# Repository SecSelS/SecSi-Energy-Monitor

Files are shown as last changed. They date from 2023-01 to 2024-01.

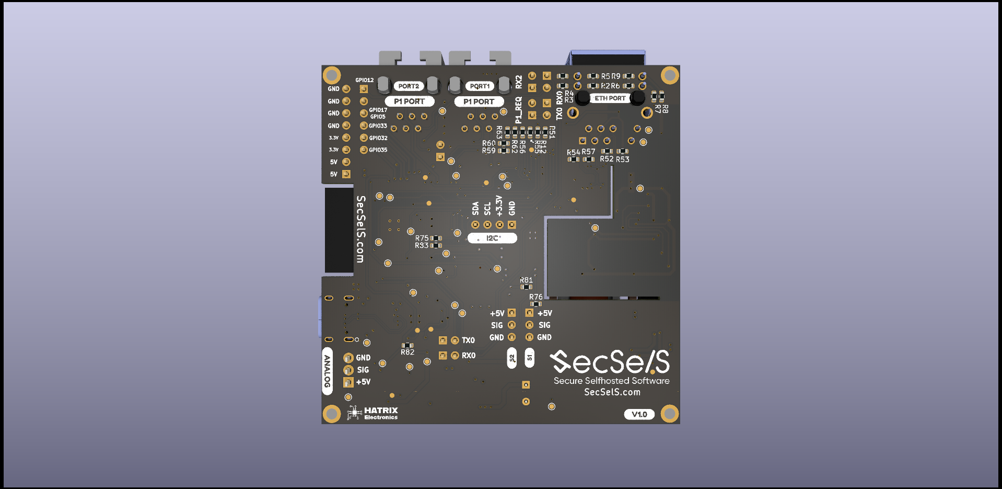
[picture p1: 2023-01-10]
Render/P1_shield_board_bottom.png

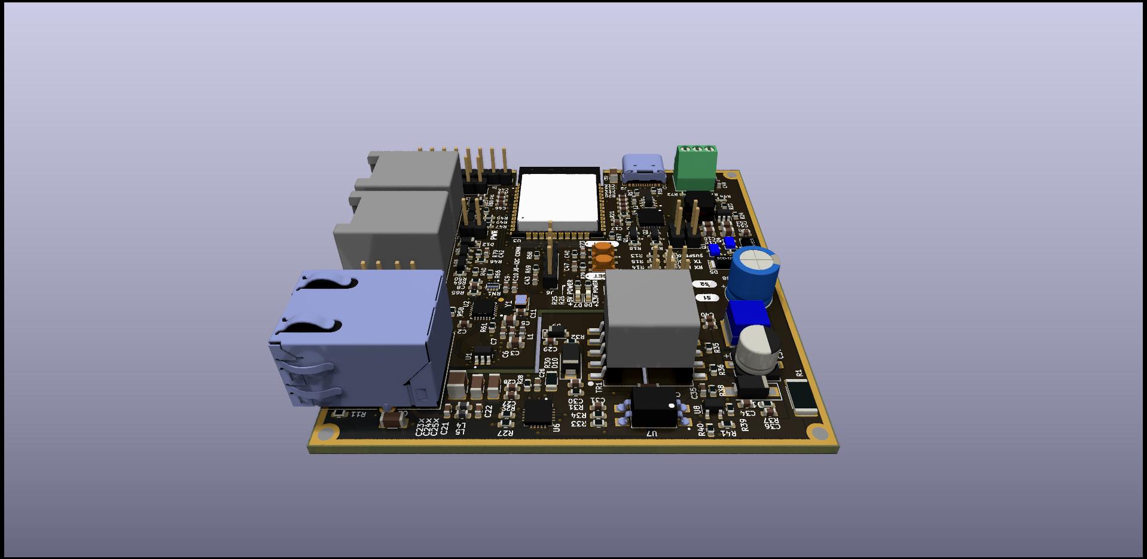
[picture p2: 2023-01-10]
Render/P1_shield_board_4.jpg

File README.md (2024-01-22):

<p align="center"><a href="https://secsels.com">SecSelS - Secure Selfhosted Software<a><p>
  
<br>
</br>
<h1 align="center" text-align="center" display="center"><a href="https://secsels.com">SecSi Energy Monitor<a></h1>

<a href="https://secsels.com">SecSelS.com</a> is a company specialized in installing, programming and inventing solutions, especially in the smart home sector. Together with <a href="https://www.luxmetering.lu/">Luxmetering</a> we invented this board to hookup every P1 meter in Luxemburg and other countries having smart meters on the P1 standard. In light of the energy-crisis and to help everyone to make his or her home or business more sustainable, we decided to opensource this device and make it compatible not only with our smart home solution, but also with other opensource smart home systems. 

You can buy a manufactured and CE-tested Version of the device for home and industry here:

<a href="https://shop.secsels.com">shop.secsels.com</a>

## Features List ##
###
* 2x P1 Port reader connected to Hardware-Uart -> read two meters precisely at the same time.
  * See the issues-sector for more information about encryptted meters
* Hardware-Uart Jumpers -> Use second Uart either for second P1, or for USB-C connection to program the board
* P1 Passthrough Jumper -> Connect either a second P1 device to the first P1, or directly to the ESP32
* Lan, Wifi and Bluetooth interfaces
* 2x Pulsecounter-Interface -> Hookup your watermeter or solar-system, and read the data.
* Additional GPIO's for additional sensors
* Multiple Powersupply options
  * P1 Port -> Directly get your supply from the P1 meter
  * POE -> Capable of POE powersupply
  * USB-C
###

## How to flash ESPHome ##
  ### Prerequisites ###
  * First make sure you have set the jumpers right for flashing. Jumpers JP7 and JP8 must be connected, UART0 is used for programming. Also make sure you don't connect any P1 device yet!
  * This tutorial is meant for the setup with <a href="https://esphome.io/">ESPHome</a>, so make sure you install it on you PC if you dont run it somewhere else. Read the guide for installing ESPHome on your PC -> https://esphome.io/guides/installing_esphome.html
  * The Yaml-Files are preprogrammed for Luxembourg, but you can alter them to work with Belgium P1 too. Also pulse counters and other devices are not included, but you can always append them to your configuration and connect them to the board. If you want to use the board for other purposes as P1 interface, you can write your own yaml of course.
  * Make sure you have <a href="https://github.com/esphome/esphome-flasher">esphome-flasher</a> installed, as the config is the easiest with that.
  * Download the <a href="#top">secsi_energy_monitor_production_lu.yaml</a> and the <a href="#top">secrets.yaml</a> to your PC.
  * If you're in Luxemburg, make sure you have your DSMR-Keys ready. In Luxemburg you can ask  your energy-provider for them per Mail.
  ### First Steps ###
  * Adjust the secrets.yaml to your data (fill in wifi data and your dsmr-key). If you don't define wifi-networks yourself but use the dashboard_import function, make sure to delete the wifi secrets.
    * On Windows you can use Notepad++ for this task, on linux use your favorite editor
    * Make sure you noted the path to your file, as you'll need it in the next step
  * Run the ESPHome commandline interface, and issue the ```run esphome secsi_energy_monitor_production_lu.yaml compile``` in your downloaded config- and secrets.yaml folder and navigate to the <NODE_NAME>/.pioenvs/<NODE_NAME>/ folder. There you will find a firmware.bin file, this is the binary you will upload.
    * Follow the instructions of the interface, and pay special attention to log output
  * Plug the Board over USB-C cable to your PC
  * Use <a href="https://github.com/esphome/esphome-flasher">esphome-flasher</a> to flash the generated config on the board. Kindly refere to their how-to.
  * If everything goes well, you now have a working P1 meter! Enjoy =)
### Additional configuration ###
  * If you use a second P1 meter, make sure to set the jumpers right! Kindly refer to the hardware documentation in the repository, and the known issues for Luxemburg
### Known issues, To be done and Limitations ###
  * When you use Ethernet, GPIO17 is not usable for external sensors/actors. He than is used as CLK_OUT so this is expected.
  
## Thank You! ##
  We wanted to thank the opensource-community and especially the developers of <a href="https://esphome.io/">ESPHome</a>! Without you, our device would not be possible! We hope that we can give back more to the community in the future. If you like our device, don't hesitate to star it =). If you don't want to configure it yourself, or have problems doing it, simply contact our company and we will find a way to help you =) -> https://secsels.com/kontakt/

<br />This work is licensed under a <a rel="license" href="http://creativecommons.org/licenses/by-sa/4.0/">Creative Commons Attribution-ShareAlike 4.0 International License</a>.

SecSels's logo and branding is used throughout this project. These brandings are Copyright protected by Franco Investments (SecSelS) and all rights are reserved. You may not distribute derivative works or products bearing the mentioned logos. Derivative works should remove all these brandings, and the license does not give any right of usage to these or other brandings used on the product.

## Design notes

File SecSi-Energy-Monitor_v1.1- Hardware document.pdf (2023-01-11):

# SecSi-Energy-Monitor

Version 1.1

Hardware document

HATRIX-ELECTRONICS

## TABLE OF CONTENTS

## 1. Introduction

SecSi-Energy-Monitor is a innovative device developed for use in smart home system. Motivation comes from need to integrate a lot of different modules on a single board and thus create more centralized system.

SecSi-Energy-Monitor provides next functionalities:

- WiFi;
- Bluetooth;
- POE (Power over Ethernet);
- Ethernet communication;
- 2x P1 Ports (Power and communication);
- I2C - for example display;
- Programming MCU over WiFi or USB-C;
- 1x Analog sensor;
- 2x Pulse sensors;
- 6x GPIOs;

## 2. Hardware considerations

P1 Shield board consists next modules (Figure 1):

1. MCU;
2. PSU;
3. POE;
4. USB to Serial converter;
5. Ethernet;
6. P1 Port;

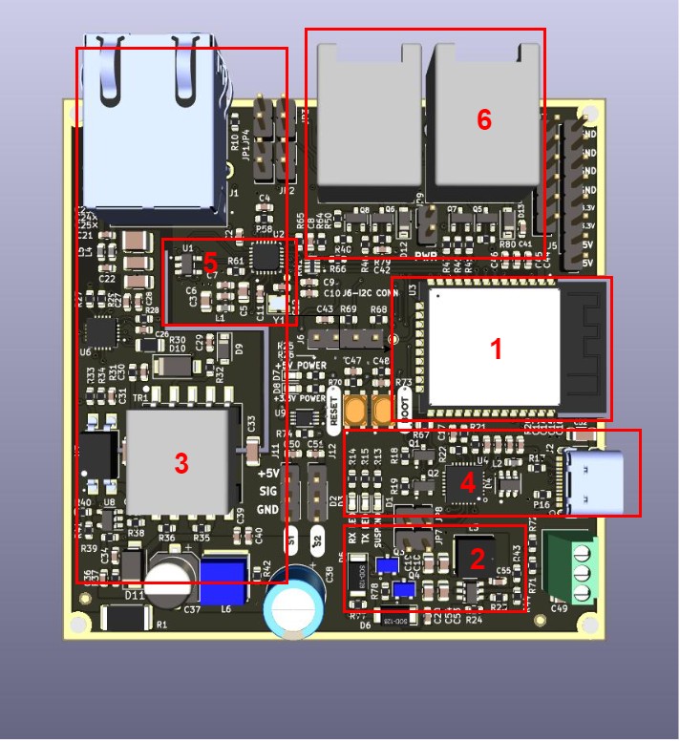
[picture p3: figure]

Figure 1: 3D View - Modules

### PSU:

The power supply of the entire board is realized with DC-DC converter (AP62200WU-7) which works in BUCK configuration. The output voltage is +3.3V and maximum output current is 2A.

DC-DC accepts 5V at it’s input from 3 different sources using control power switch implemented with two P-type mosfets. Source with the highest priority is POE, followed by USB, and the lowest priority is P1 Port. Source selection is done automatically. There is no conflicts if only one source is connected or if combinations of sources are connected.

### POE:

POE can be used to power the board. Segment is realized using IC (SI3404) whose role is to convert input voltage from RJ45 and adjust it for use. The POE standard applied to the board is IEEE 802.3 Type 1 and the board is galvanic isolated (1.5kV) using a transformer.

### USB to Serial:

Module is used for communication and programming of the microcontroller that is placed on the board. Its role is to convert communication between USB and UART. An important item added to this module is the auto-boot function. Auto-boot function represents programming without pressing the boot button, you only need to connect the USB and start programming, the board will do the rest and inform you when programming is finished.

### Ethernet:

Ethernet is designed for speed’s up to 100Mb/s in configuration “Auto-negotiation enabled”.

### P1 Port:

Module is used for providing power to board and communication using P1 port specification with communication baud rate up to 115 200.

## 3. Software consideration

### MCU-ESP32:

MCU is the most important part of the board, it controls and communicates with the modules. ESP32 has integrated Wi-Fi and Bluetooth communication. Programming of the controller is done using USB through a USB to Serial converter. There are two push-buttons on the board, BOOT and RESET. The reset button resets the controller, while the boot button is used during programming. Next figure represents device block diagram and pinout (Figure 2):

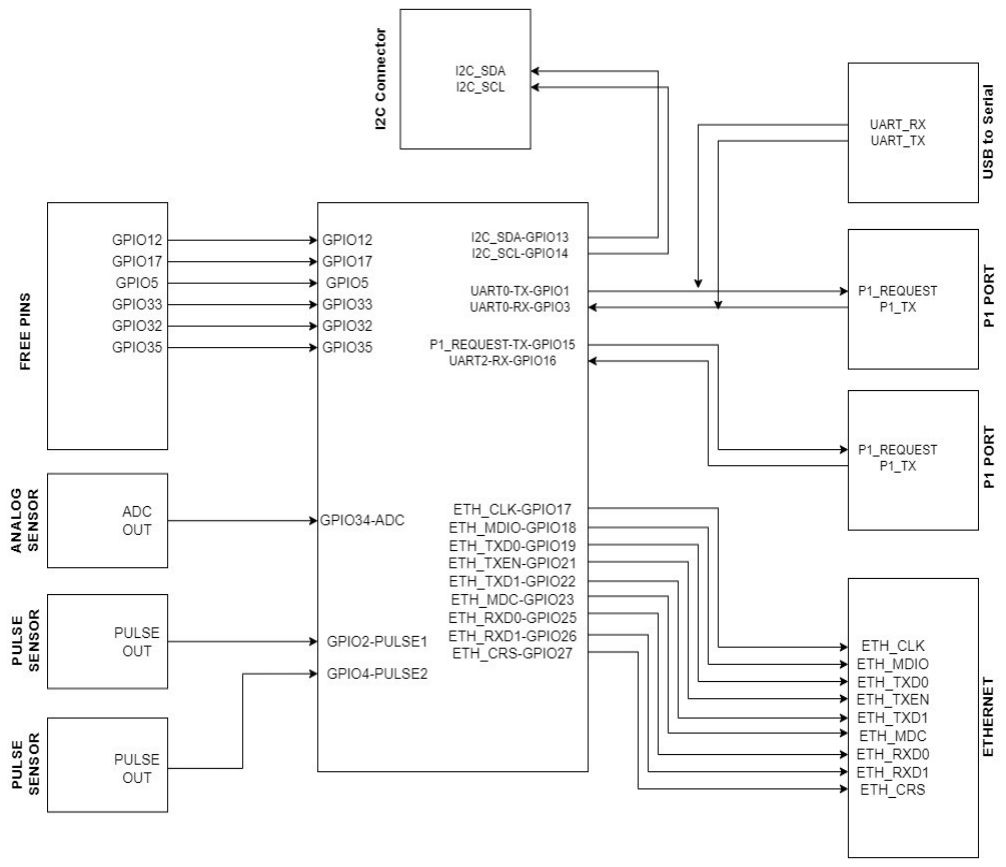
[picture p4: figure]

Figure 2: Block diagram and pinout

ESP32 uses UART, I2C and RMII interface (Ethernet) for communication with modules.

When programming or communicating with the board, jumpers JP7 and JP8 must be placed. UART0 is used for programming.

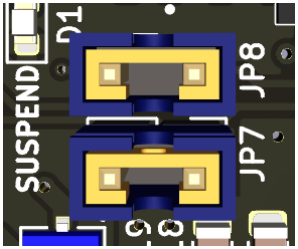
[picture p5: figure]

Figure 3: USB Programming of ESP32

4-pin header on board contains I2C communication pinout with power supply pins (connector J6). It can be used for displays or sensors. There is a +3.3V power supply on the connector and communication voltage level must be +3.3V.

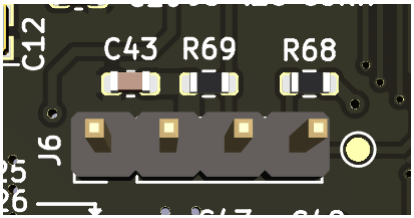
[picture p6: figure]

Figure 4: I2C header

Board has the possibility to connect one analog sensor. Sensor is connected to the terminal block connector (J10) and the connector has a +5V power supply. Maximum input voltage from sensor is 5V.

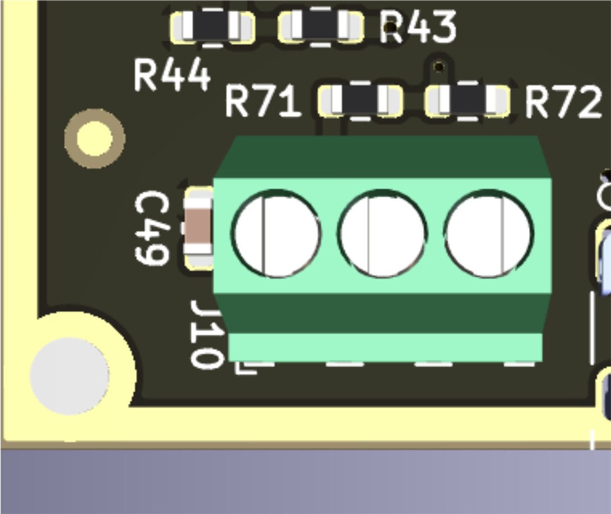
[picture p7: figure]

Figure 5: Terminal block for analog sensor

Pulse sensors can be connected to header connectors (J11 and J12). The power supply at connectors is +5V. Pulse sensors are designed for maximum 5V input voltage.

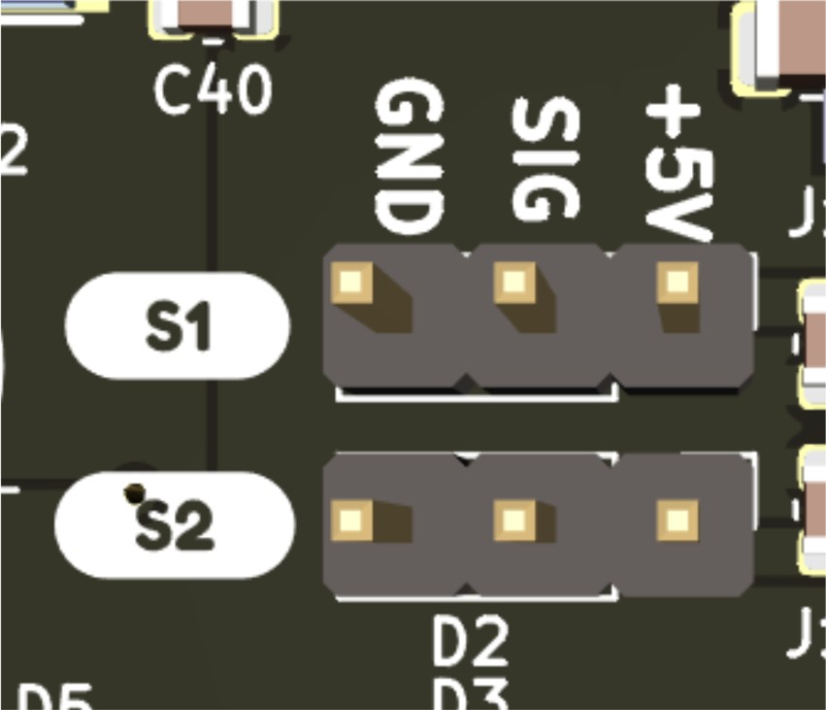
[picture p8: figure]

Figure 6: Headers for pulse sensors

Free pins are connected to header connector (J7), power supply pinout is placed on the header connector (J5) and contains 2x +3.3V and 2x +5V power supplies.

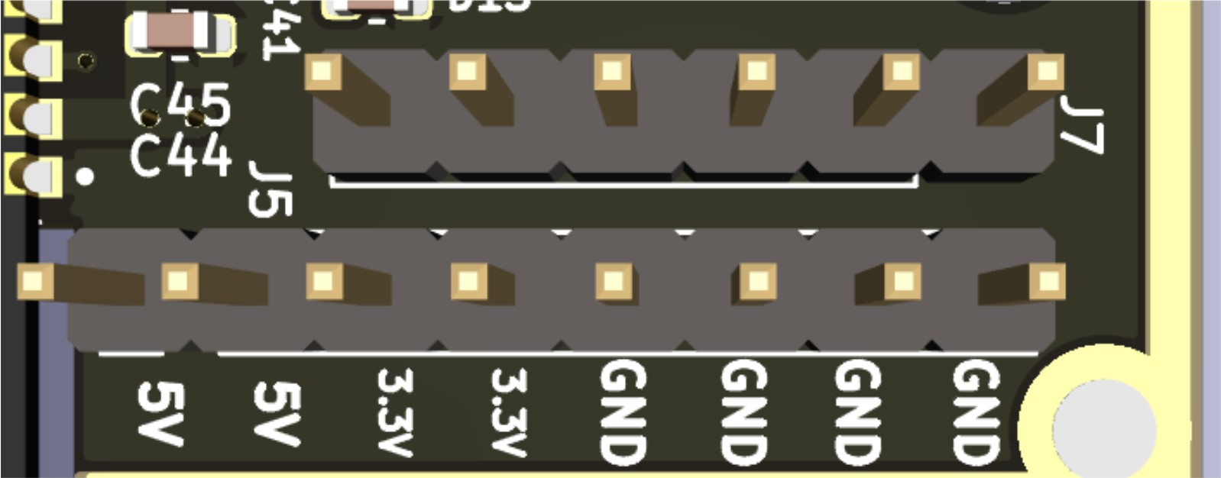
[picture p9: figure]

Figure 7: Free pins and power supply pins for free use

### P1 Port:

P1 Port is used for communication with external modules that send data of consumption and the status of devices connected to them. There are two P1 ports on the board.

One P1 port (J4) is the main one and it has direct communication with ESP32 via UART2. The second P1 port (J3) can be separate, sharing UART0 with the programming part or it can be a continuation of the main P1 Port.

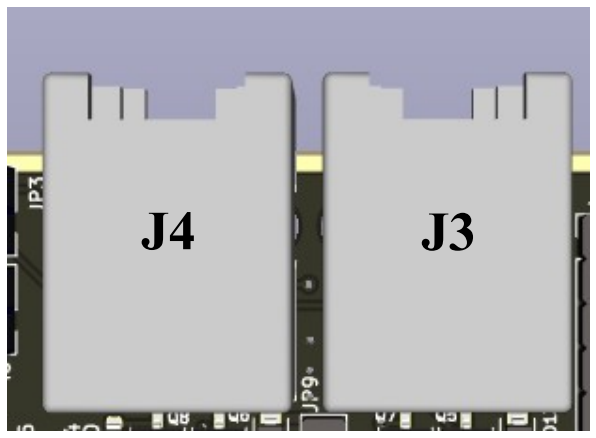
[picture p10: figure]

Figure 8: P1 port connectors

In the configuration where the second P1 Port (J3) is independent, it is necessary to place jumpers JP2 and JP4. In that configuration, it is necessary to remove USB jumpers JP7 and JP8 so UART0 can be free to be used from second P1 Port. Communication between ESP32 and P1 Port is done via UART0.

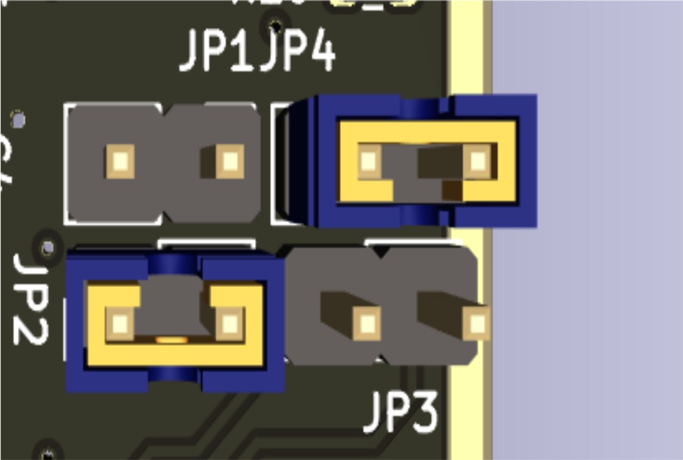
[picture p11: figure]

Figure 9: Second P1 port jumpers configuration – Independent mode

In the configuration where the second P1 Port is an extension of the main P1 Port, the information coming to the main P1 Port is also forwarded to the second one. Then it is necessary to place jumpers JP1 and JP3, as well as the jumper for the power supply JP9 if necessary.

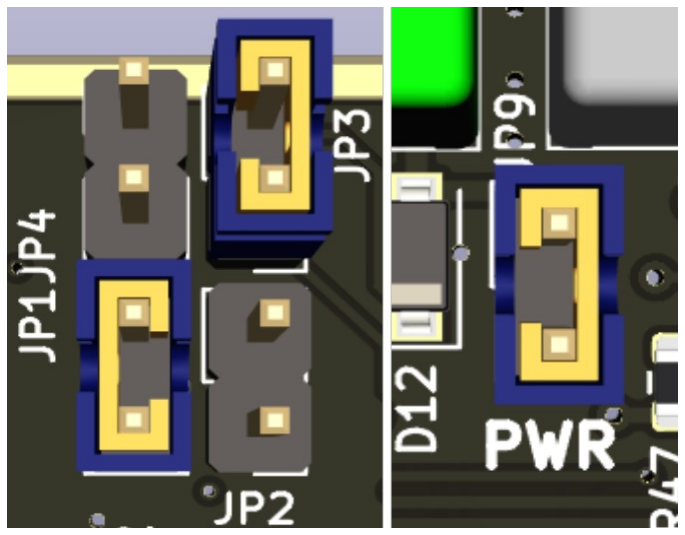
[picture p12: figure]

Figure 10: Second P1 port jumpers configuration – Continuation mode

## 4. Datasheet

MCU-ESP32:

https://www.espressif.com/sites/default/files/documentation/esp32-wroom-32e_esp32-wroom-32ue_datasheet_en.pdf (https://www.espressif.com/sites/default/files/documentation/esp32-wroom-32e_esp32-wroom-32ue_datasheet_en.pdf)

POE-SI3404:

https://www.skyworksinc.com/-/media/Skyworks/SL/documents/public/data-sheets/si3404-datasheet.pdf (https://www.skyworksinc.com/-/media/Skyworks/SL/documents/public/data-sheets/si3404-datasheet.pdf)

Ethernet-LAN8720:

https://ww1.microchip.com/downloads/aemDocuments/documents/OTH/ProductDocuments/DataSheets/00002165B.pdf (https://ww1.microchip.com/downloads/aemDocuments/documents/OTH/ProductDocuments/DataSheets/00002165B.pdf)

USB to Serial-CP2102:

https://www.silabs.com/documents/public/data-sheets/CP2102-9.pdf

PSU-AP62200WU-7:

https://www.diodes.com/assets/Datasheets/AP62200_AP62201_AP62200T.pdf

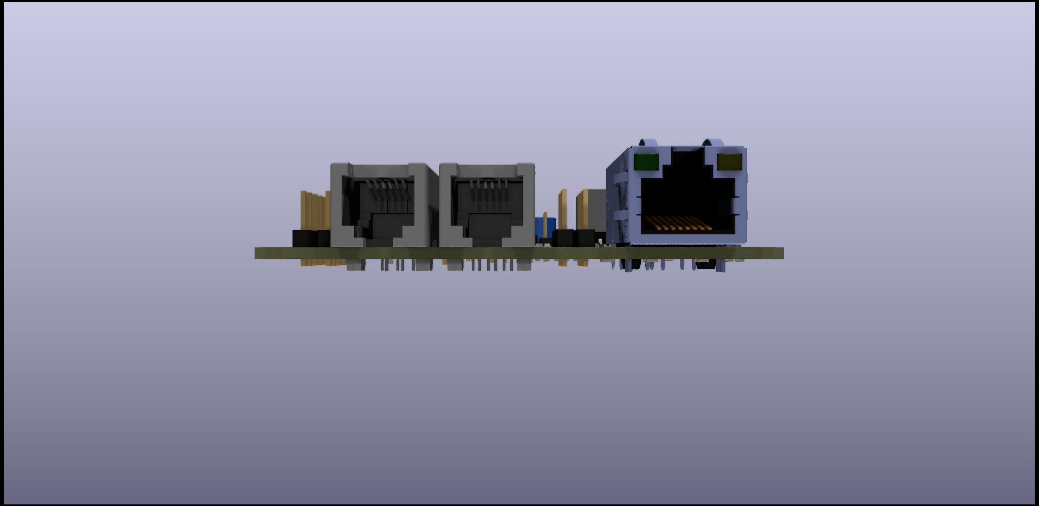
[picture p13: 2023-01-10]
Render/P1_shield_board_3.png

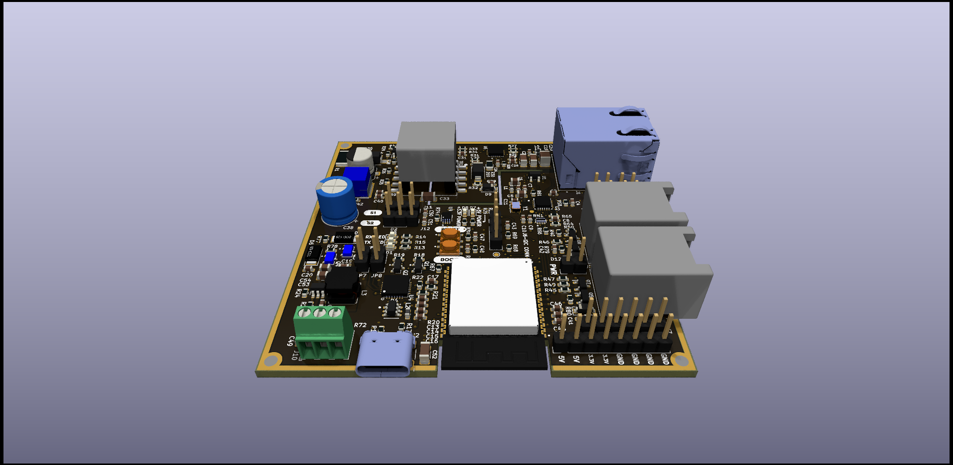
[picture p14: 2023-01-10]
Render/P1_shield_board_2.png

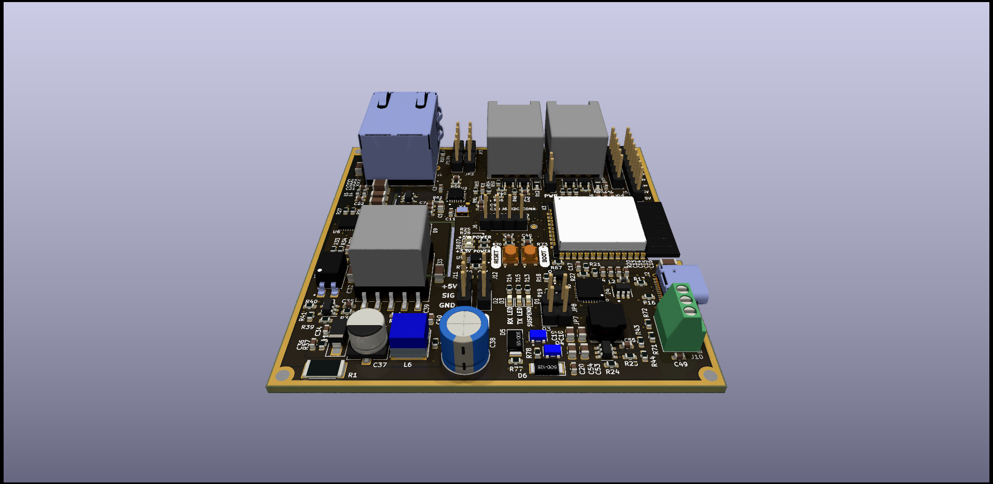
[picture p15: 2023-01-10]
Render/P1_shield_board_1.png

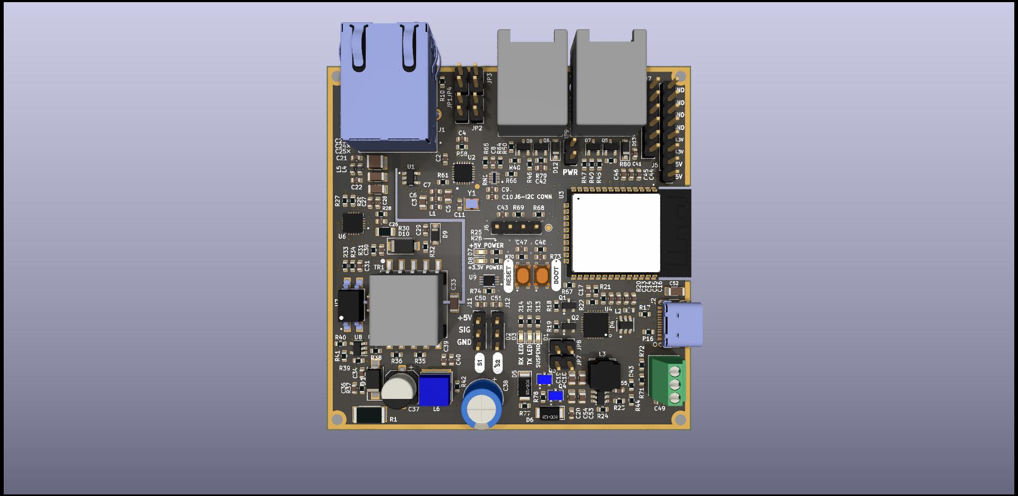
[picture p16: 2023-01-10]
Render/P1_shield_board_top.jpg

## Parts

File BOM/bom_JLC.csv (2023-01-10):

Designator | Footprint | Quantity | Value | LCSC Part #
U2 | Microchip-LAN8720AI-CP-TR-0-0-IPC_B | 1 | LAN8720A | C17146

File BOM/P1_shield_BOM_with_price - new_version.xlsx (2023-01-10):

 |  | Bill of Materials for SecSi-Energy-Monitor
 |  | Source Data From: |  | P1_shield_board.kicad_pro
 |  | Variant: |  | None
 |  | Report Date: |  | 10/22/2022 20:26
 |  |  |  |  | Primary
Vault P/N | Designator | Description | Qty | Value | Supplier | Supplier Part Number | Manufacturer | Manufacturer Part Number | Link DigiKey | Price | Total Price
1 | C6, C7, C8, C14, C16, C26, C46, C55 | C_0603_1608Metric | 8 | 0.1uF | DigiKey | 1276-1006-1-ND | Samsung Electro-Mechanics | CL10B104KA8NNNC | https://www.digikey.lu/en/products/detail/samsung-electro-mechanics/CL10B104KA8NNNC/3886664 | EUR 0.10 | EUR 0.80
2 | C10, C15, C17, C43, C45, C49, C50, C51 | C_0603_1608Metric | 8 | 1uF | DigiKey | 1276-1102-1-ND | Samsung Electro-Mechanics | CL10A105KA8NNNC | https://www.digikey.lu/en/products/detail/samsung-electro-mechanics/CL10A105KA8NNNC/3886760 | EUR 0.10 | EUR 0.80
3 | C1, C32, C33, C52 | C_1206_3216Metric | 4 | 1nF/2KV | DigiKey | 478-7023-1-ND | KYOCERA AVX | 1206GC102KAT2A | https://www.digikey.lu/en/products/detail/kyocera-avx/1206GC102KAT2A/3247523 | EUR 0.25 | EUR 1.00
4 | C3, C5, C18, C19 | C_0805_2012Metric | 4 | 22uF | DigiKey | 1276-2910-1-ND | Samsung Electro-Mechanics | CL21A226MPQNNNE | https://www.digikey.de/en/products/detail/samsung-electro-mechanics/CL21A226MPQNNNE/3888568 | EUR 0.19 | EUR 0.76
5 | C22, C27, C28 | C_0603_1608Metric | 3 | 100nF/100V | DigiKey | 1276-6807-1-ND | Samsung Electro-Mechanics | CL10B104KC8NNNC | https://www.digikey.lu/en/products/detail/samsung-electro-mechanics/CL10B104KC8NNNC/5961291 | EUR 0.10 | EUR 0.30
6 | C20, C44 | C_0603_1608Metric | 2 | 10uF | DigiKey | 1276-1871-1-ND | Samsung Electro-Mechanics | CL10A106MP8NNNC | https://www.digikey.lu/en/products/detail/samsung-electro-mechanics/CL10A106MP8NNNC/3887529 | EUR 0.19 | EUR 0.38
7 | C29, C36 | C_0603_1608Metric | 2 | 1uF/25V | DigiKey | 1276-1102-1-ND | Samsung Electro-Mechanics | CL10A105KA8NNNC | https://www.digikey.lu/en/products/detail/samsung-electro-mechanics/CL10A105KA8NNNC/3886760 | EUR 0.10 | EUR 0.20
8 | C39, C40 | C_0603_1608Metric | 2 | 22uF/10V | DigiKey | 1276-1274-1-ND | Samsung Electro-Mechanics | CL10A226MP8NUNE | https://www.digikey.lu/en/products/detail/samsung-electro-mechanics/CL10A226MP8NUNE/3886932 | EUR 0.19 | EUR 0.38
9 | C41, C42 | C_0603_1608Metric | 2 | 10uF/10V | DigiKey | 1276-1871-1-ND | Samsung Electro-Mechanics | CL10A106MP8NNNC | https://www.digikey.lu/en/products/detail/samsung-electro-mechanics/CL10A106MP8NNNC/3887529 | EUR 0.19 | EUR 0.38
10 | C53, C54 | C_0805_2012Metric | 2 | 10uF | DigiKey | 311-2085-1-ND | YAGEO | CC0805ZKY5V7BB106 | https://www.digikey.de/en/products/detail/yageo/CC0805ZKY5V7BB106/5884301 | EUR 0.26 | EUR 0.52
11 | C2 | C_0603_1608Metric | 1 | 100nF/16V | DigiKey | 1276-1006-1-ND | Samsung Electro-Mechanics | CL10B104KA8NNNC | https://www.digikey.lu/en/products/detail/samsung-electro-mechanics/CL10B104KA8NNNC/3886664 | EUR 0.10 | EUR 0.10
12 | C4 | C_0603_1608Metric | 1 | 100pF | DigiKey | 478-06033A101JAT2ACT-ND | KYOCERA AVX | 06033A101JAT2A | https://www.digikey.lu/en/products/detail/kyocera-avx/06033A101JAT2A/1599070 | EUR 0.10 | EUR 0.10
13 | C9 | C_0603_1608Metric | 1 | 470pF | DigiKey | 311-4073-1-ND | YAGEO | CC0603KRX7R7BB471 | https://www.digikey.de/en/products/detail/yageo/CC0603KRX7R7BB471/5883765 | EUR 0.10 | EUR 0.10
14 | C13 | C_0603_1608Metric | 1 | 4.7uF | DigiKey | 1276-1044-1-ND | Samsung Electro-Mechanics | CL10A475KP8NNNC | https://www.digikey.lu/en/products/detail/samsung-electro-mechanics/CL10A475KP8NNNC/3886702 | EUR 0.10 | EUR 0.10
15 | C21 | C_0603_1608Metric | 1 | 1nF/100V | DigiKey | 445-2312-1-ND | TDK Corporation | C1608C0G2A102J080AA | https://www.digikey.lu/en/products/detail/tdk-corporation/C1608C0G2A102J080AA/789706 | EUR 0.19 | EUR 0.19
16 | C23 | C_1210_3225Metric | 1 | 10uF/100V | DigiKey | 1276-CL32Y106KCVZNWECT-ND | Samsung Electro-Mechanics | CL32Y106KCVZNWE | https://www.digikey.lu/en/products/detail/samsung-electro-mechanics/CL32Y106KCVZNWE/15992073 | EUR 1.12 | EUR 1.12
17 | C24 | C_1206_3216Metric | 1 | 4.7uF/100V | DigiKey | 490-GRM31CC72A475KE11KCT-ND | Murata Electronics | GRM31CC72A475KE11K | https://www.digikey.lu/en/products/detail/murata-electronics/GRM31CC72A475KE11K/13904926 | EUR 0.85 | EUR 0.85
18 | C25 | C_1206_3216Metric | 1 | 1uF/100V | DigiKey | 1276-1838-1-ND | Samsung Electro-Mechanics | CL31B105KCHNNNE | digikey.lu/en/products/detail/samsung-electro-mechanics/CL31B105KCHNNNE/3887496 | EUR 0.20 | EUR 0.20
19 | C30 | C_0603_1608Metric | 1 | 10nF/100V | DigiKey | 445-1304-1-ND | TDK Corporation | C1608X7R2A103K080AA | https://www.digikey.lu/en/products/detail/tdk-corporation/C1608X7R2A103K080AA/513829 | EUR 0.10 | EUR 0.10
20 | C31 | C_0603_1608Metric | 1 | 1uF/6.3V | DigiKey | 1276-1102-1-ND | Samsung Electro-Mechanics | CL10A105KA8NNNC | https://www.digikey.lu/en/products/detail/samsung-electro-mechanics/CL10A105KA8NNNC/3886760 | EUR 0.10 | EUR 0.10
21 | C34 | C_0603_1608Metric | 1 | 1.5nF/50V | DigiKey | 1276-6666-1-ND | Samsung Electro-Mechanics | CL10B152KB8WPNC | https://www.digikey.lu/en/products/detail/samsung-electro-mechanics/CL10B152KB8WPNC/5961150 | EUR 0.10 | EUR 0.10
22 | C35 | C_0603_1608Metric | 1 | 1.5nF | DigiKey | 311-3996-1-ND | YAGEO | CC0603JRX7R8BB152 | https://www.digikey.lu/en/products/detail/yageo/CC0603JRX7R8BB152/5883657 | EUR 0.11 | EUR 0.11
23 | C37 | CP_Elec_6.3x5.9 | 1 | 100uF/16V | DigiKey | 3222-SVL1CM101E06E00RS153CT-ND | Aishi Capacitors (Hunan Aihua Group | SVL1CM101E06E00RS153 | https://www.digikey.lu/en/products/detail/aishi-capacitors/SVL1CM101E06E00RS153/16536384 | EUR 0.36 | EUR 0.36
24 | C38 | CP_Radial_D8.0mm_P3.50mm | 1 | 1000uF/10V | DigiKey | 1189-1050-ND | Rubycon | 10PK1000MEFC8X11.5 | https://www.digikey.de/en/products/detail/rubycon/10PK1000MEFC8X11-5/3133980 | EUR 0.46 | EUR 0.46
25 | C47, C48, C11 | C_0603_1608Metric | 3 | 100nF/DNP | DigiKey | 1276-1006-1-ND | Samsung Electro-Mechanics | CL10B104KA8NNNC | https://www.digikey.lu/en/products/detail/samsung-electro-mechanics/CL10B104KA8NNNC/3886664 | EUR 0.10 | EUR 0.30
26 | R2, R7, R34, R38, R42, R64, R66, R75 | R_0603_1608Metric | 8 | 0R | DigiKey | P0.0GCT-ND | Panasonic Electronic Components | ERJ-3GEY0R00V | https://www.digikey.lu/en/products/detail/panasonic-electronic-components/ERJ-3GEY0R00V/135656 | EUR 0.10 | EUR 0.80
27 | R3, R6, R35, R36, R67, R83, R82 | R_0603_1608Metric | 7 | 0R/DNP | DigiKey | P0.0GCT-ND | Panasonic Electronic Components | ERJ-3GEY0R00V | https://www.digikey.lu/en/products/detail/panasonic-electronic-components/ERJ-3GEY0R00V/135656 | EUR 0.10 | EUR 0.70
28 | R13, R14, R15, R22, R25, R26, R45, R46, R47, R48, R79, R80 | R_0603_1608Metric | 12 | 1K | DigiKey | 541-1.0KGCT-ND | Vishay Dale | CRCW06031K00JNEA | https://www.digikey.lu/en/products/detail/vishay-dale/CRCW06031K00JNEA/1174229 | EUR 0.10 | EUR 1.20
29 | R18, R19, R44, R49, R50, R70, R71, R72, R73 | R_0603_1608Metric | 9 | 10K | DigiKey | YAG1290CT-ND | YAGEO | RC0603FR-0710KP | digikey.lu/en/products/detail/yageo/RC0603FR-0710KP/4935305 | EUR 0.10 | EUR 0.90
30 | R77, R78 | R_0603_1608Metric | 2 | 10K/DNP | DigiKey | YAG1290CT-ND | YAGEO | RC0603FR-0710KP | digikey.lu/en/products/detail/yageo/RC0603FR-0710KP/4935305 | EUR 0.10 | EUR 0.20
31 | R12, R55, R58, R59, R62 | R_0603_1608Metric | 5 | 4.75K/1% | DigiKey | 311-4.75KHRCT-ND | YAGEO | RC0603FR-074K75L | https://www.digikey.de/en/products/detail/yageo/RC0603FR-074K75L/727215 | EUR 0.10 | EUR 0.50
32 | R51, R56, R60, R63 | R_0603_1608Metric | 4 | 4.75K/1%/DNP | DigiKey | 311-4.75KHRCT-ND | YAGEO | RC0603FR-074K75L | https://www.digikey.de/en/products/detail/yageo/RC0603FR-074K75L/727215 | EUR 0.10 | EUR 0.40
33 | R4, R9 | R_0603_1608Metric | 2 | 330R | DigiKey | 1292-WR06X331JTLCT-ND | Walsin Technology Corporation | WR06X331 JTL | https://www.digikey.de/en/products/detail/walsin-technology-corporation/WR06X331-JTL/13240667 | EUR 0.10 | EUR 0.20
34 | R5, R8 | R_0603_1608Metric | 2 | 330R/DNP | DigiKey | 1292-WR06X331JTLCT-ND | Walsin Technology Corporation | WR06X331 JTL | https://www.digikey.de/en/products/detail/walsin-technology-corporation/WR06X331-JTL/13240667 | EUR 0.10 | EUR 0.20
35 | R52, R53, R54, R57 | R_0603_1608Metric | 4 | 49.9R | DigiKey | 13-RC0603FR-1349R9LCT-ND | YAGEO | RC0603FR-1349R9L | https://www.digikey.de/en/products/detail/yageo/RC0603FR-1349R9L/13694149 | EUR 0.10 | EUR 0.40
36 | R10 | R_0603_1608Metric | 1 | 4.75K | DigiKey | 311-4.75KHRCT-ND | YAGEO | RC0603FR-074K75L | https://www.digikey.de/en/products/detail/yageo/RC0603FR-074K75L/727215 | EUR 0.10 | EUR 0.10
37 | R11 | R_0603_1608Metric | 1 | 4.75K/DNP | DigiKey | 311-4.75KHRCT-ND | YAGEO | RC0603FR-074K75L | https://www.digikey.de/en/products/detail/yageo/RC0603FR-074K75L/727215 | EUR 0.10 | EUR 0.10
38 | R16, R17 | R_0603_1608Metric | 2 | 5.1K | DigiKey | YAG3682CT-ND | YAGEO | AC0603JR-075K1L | digikey.lu/en/products/detail/yageo/AC0603JR-075K1L/5896480 | EUR 0.10 | EUR 0.20
39 | R68, R69, | R_0603_1608Metric | 2 | 4.7K | DigiKey | 541-4.7KGCT-ND | Vishay Dale | CRCW06034K70JNEA | https://www.digikey.lu/en/products/detail/vishay-dale/CRCW06034K70JNEA/1174245 | EUR 0.10 | EUR 0.20
40 | R76, R81 | R_0603_1608Metric | 2 | 4.7K/DNP | DigiKey | 541-4.7KGCT-ND | Vishay Dale | CRCW06034K70JNEA | https://www.digikey.lu/en/products/detail/vishay-dale/CRCW06034K70JNEA/1174245 | EUR 0.10 | EUR 0.20
41 | R1 | R_2512_6332Metric | 1 | 10M | DigiKey | A121122CT-ND | TE Connectivity Passive Product | 352210MJT | https://www.digikey.de/en/products/detail/te-connectivity-passive-product/352210MJT/5244973 | EUR 0.66 | EUR 0.66
42 | R20 | R_0603_1608Metric | 1 | 22.1K | DigiKey | P22.1KHCT-ND | Panasonic Electronic Components | ERJ-3EKF2212V | https://www.digikey.lu/en/products/detail/panasonic-electronic-components/ERJ-3EKF2212V/196218 | EUR 0.10 | EUR 0.10
43 | R21 | R_0603_1608Metric | 1 | 47.5K | DigiKey | P47.5KHCT-ND | Panasonic Electronic Components | ERJ-3EKF4752V | https://www.digikey.lu/en/products/detail/panasonic-electronic-components/ERJ-3EKF4752V/196371 | EUR 0.10 | EUR 0.10
44 | R23 | R_0603_1608Metric | 1 | 69.8K/1% | DigiKey | 311-69.8KHRCT-ND | YAGEO | RC0603FR-0769K8L | https://www.digikey.de/en/products/detail/yageo/RC0603FR-0769K8L/727360 | EUR 0.10 | EUR 0.10
45 | R24 | R_0603_1608Metric | 1 | 22.1K/1% | DigiKey | P22.1KHCT-ND | Panasonic Electronic Components | ERJ-3EKF2212V | https://www.digikey.lu/en/products/detail/panasonic-electronic-components/ERJ-3EKF2212V/196218 | EUR 0.10 | EUR 0.10
46 | R27 | R_0603_1608Metric | 1 | 88.7K/1% | DigiKey | 13-AC0603FR-0788K7LCT-ND | YAGEO | AC0603FR-0788K7L | https://www.digikey.lu/en/products/detail/yageo/AC0603FR-0788K7L/5896319 | EUR 0.10 | EUR 0.10
47 | R28 | R_0603_1608Metric | 1 | 24.3K/1% | DigiKey | 13-RT0603FRE0724K3LCT-ND | YAGEO | RT0603FRE0724K3L | https://www.digikey.lu/en/products/detail/yageo/RT0603FRE0724K3L/1075231 | EUR 0.10 | EUR 0.10
48 | R29 | R_0603_1608Metric | 1 | 48.7R/1% | DigiKey | 738-RMCF0603FT48R7CT-ND | Stackpole Electronics Inc | RMCF0603FT48R7 | https://www.digikey.lu/en/products/detail/stackpole-electronics-inc/RMCF0603FT48R7/1761149 | EUR 0.10 | EUR 0.10
49 | R30 | R_1206_3216Metric | 1 | 0.62R | DigiKey | A109861CT-ND | TE Connectivity Passive Product | RLP73K2BR62JTD | https://www.digikey.lu/en/products/detail/te-connectivity-passive-product/RLP73K2BR62JTD/4032236 | EUR 0.32 | EUR 0.32
50 | R31 | R_0603_1608Metric | 1 | 82K | DigiKey | 311-82KGRCT-ND | YAGEO | RC0603JR-0782KL | https://www.digikey.de/en/products/detail/yageo/RC0603JR-0782KL/726835 | EUR 0.10 | EUR 0.10
51 | R32 | R_0603_1608Metric | 1 | 10R | DigiKey | 13-AF0603FR-0710RLCT-ND | YAGEO | AF0603FR-0710RL | https://www.digikey.lu/en/products/detail/yageo/AF0603FR-0710RL/5900867 | EUR 0.10 | EUR 0.10
52 | R33 | R_0603_1608Metric | 1 | 4.99K/1% | DigiKey | 311-4.99KHRCT-ND | YAGEO | RC0603FR-074K99L | https://www.digikey.de/en/products/detail/yageo/RC0603FR-074K99L/727219 | EUR 0.10 | EUR 0.10
53 | R37 | R_0603_1608Metric | 1 | 8.2R | DigiKey | 541-8.20HHCT-ND | Vishay Dale | CRCW06038R20FKEA | https://www.digikey.lu/en/products/detail/vishay-dale/CRCW06038R20FKEA/1961641 | EUR 0.10 | EUR 0.10
54 | R39 | R_0603_1608Metric | 1 | 360R | DigiKey | 13-RT0603FRE07360RLCT-ND | YAGEO | RT0603FRE07360RL | https://www.digikey.lu/en/products/detail/yageo/RT0603FRE07360RL/1075325 | EUR 0.10 | EUR 0.10
55 | R40 | R_0603_1608Metric | 1 | 36.5K | DigiKey | 311-36.5KHRCT-ND | YAGEO | RC0603FR-0736K5L | https://www.digikey.de/en/products/detail/yageo/RC0603FR-0736K5L/727181 | EUR 0.10 | EUR 0.10
56 | R41 | R_0603_1608Metric | 1 | 12.1K | DigiKey | P12.1KHCT-ND | Panasonic Electronic Components | ERJ-3EKF1212V | https://www.digikey.lu/en/products/detail/panasonic-electronic-components/ERJ-3EKF1212V/196099 | EUR 0.10 | EUR 0.10
57 | R43 | R_0603_1608Metric | 1 | 14K | DigiKey | 311-14.0KHRCT-ND | YAGEO | RC0603FR-0714KL | https://www.digikey.de/en/products/detail/yageo/RC0603FR-0714KL/726941 | EUR 0.10 | EUR 0.10
58 | R61 | R_0603_1608Metric | 1 | 12.1K/1% | DigiKey | P12.1KHCT-ND | Panasonic Electronic Components | ERJ-3EKF1212V | https://www.digikey.lu/en/products/detail/panasonic-electronic-components/ERJ-3EKF1212V/196099 | EUR 0.10 | EUR 0.10
59 | R65 | R_0603_1608Metric | 1 | 1.5K/1% | DigiKey | 311-1.5KGRCT-ND | YAGEO | RC0603JR-071K5L | https://www.digikey.de/en/products/detail/yageo/RC0603JR-071K5L/726689 | EUR 0.10 | EUR 0.10
60 | R74 | R_0603_1608Metric | 1 | 200K | DigiKey | 311-200KGRCT-ND | YAGEO | RC0603JR-07200KL | https://www.digikey.de/en/products/detail/yageo/RC0603JR-07200KL/726738 | EUR 0.10 | EUR 0.10
61 | L4, L5 | L_0603_1608Metric | 2 | 470 Ohm/100MHz | DigiKey | 732-4667-1-ND | Würth Elektronik | 742792645 | https://www.digikey.lu/en/products/detail/w%C3%BCrth-elektronik/742792645/4310432 | EUR 0.19 | EUR 0.38
62 | L1 | L_0603_1608Metric | 1 | 100Ohm/100MHz | DigiKey | 283-MFBW1V1608-101-RCT-ND | Eaton - Electronics Division | MFBW1V1608-101-R | https://www.digikey.de/en/products/detail/eaton-electronics-division/MFBW1V1608-101-R/13161064 | EUR 0.10 | EUR 0.10
63 | L2 | L_0603_1608Metric | 1 | FERRITE BEAD 30 OHM | DigiKey | 240-2374-1-ND | Laird-Signal Integrity Products | MI0603L301R-10 | https://www.digikey.lu/en/products/detail/laird-signal-integrity-products/MI0603L301R-10/806613 | EUR 0.22 | EUR 0.22
64 | L3 | NRS5030T3R3MMGJ | 1 | 3.3uH | DigiKey | 587-3459-1-ND | Taiyo Yuden | NRS5030T3R3MMGJ | https://www.digikey.de/en/products/detail/taiyo-yuden/NRS5030T3R3MMGJ/4157847 | EUR 0.36 | EUR 0.36
65 | L6 | INDPM6060X470N | 1 | 3.3uH/DNP | DigiKey | 118-SRN6045HA-3R3YCT-ND | Bourns Inc. | SRN6045HA-3R3Y | https://www.digikey.lu/en/products/detail/bourns-inc/SRN6045HA-3R3Y/15219550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 | EUR 0.67 | EUR 0.67
66 | D3, D7, D8 | LED_0603_1608Metric | 3 | LED_Filled | DigiKey | 3147-B1911PG--20D000514U1930CT-ND | Harvatek Corporation | B1911PG--20D000514U1930 | https://www.digikey.lu/en/products/detail/harvatek-corporation/B1911PG-20D000514U1930/15519992 | EUR 0.10 | EUR 0.30
67 | D12, D13 | D_SOD-123 | 2 | MBRX120LF-TP | DigiKey | MBRX120LF-TPMSCT-ND | Micro Commercial Co | MBRX120LF-TP | https://www.digikey.de/en/products/detail/micro-commercial-co/MBRX120LF-TP/2041507 | EUR 0.45 | EUR 0.90
68 | D9 | D_SOD-123 | 1 | 1N4148W | DigiKey | 1655-1N4148WCT-ND | SMC Diode Solutions | 1N4148W | https://www.digikey.lu/en/products/detail/smc-diode-solutions/1N4148W/6022450 | EUR 0.15 | EUR 0.15
69 | D5, D6 | D_SOD-128 | 2 | RB088LAM-40TR | DigiKey | 846-RB088LAM-40CT-ND | Rohm Semiconductor | RB088LAM-40TR | https://www.digikey.lu/en/products/detail/rohm-semiconductor/RB088LAM-40TR/13532515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 | EUR 0.55 | EUR 1.10
70 | D1 | LED_0603_1608Metric | 1 | RED | DigiKey | 3147-B1931URO-20D000114U1930CT-ND | Harvatek Corporation | B1931URO-20D000114U1930 | https://www.digikey.lu/en/products/detail/harvatek-corporation/B1931URO-20D000114U1930/15910603 | EUR 0.10 | EUR 0.10
71 | D2 | LED_0603_1608Metric | 1 | YELLOW | DigiKey | 732-4981-1-ND | Würth Elektronik | 150060YS75000 | https://www.digikey.lu/en/products/detail/w%C3%BCrth-elektronik/150060YS75000/4489909 | EUR 0.16 | EUR 0.16
72 | D4 | ON_Semiconductor-318G-02-06_2012-V-IPC_B | 1 | NUP4114HMR6T1G | DigiKey | NUP4114HMR6T1GOSCT-ND | onsemi | NUP4114HMR6T1G | https://www.digikey.de/en/products/detail/onsemi/NUP4114HMR6T1G/1961292 | EUR 0.67 | EUR 0.67
73 | D10 | D_SMA | 1 | RS1B-E3/61T | DigiKey | RS1B-E3/61TGICT-ND | Vishay General Semiconductor - Diodes Division | RS1B-E3/61T | https://www.digikey.lu/en/products/detail/vishay-general-semiconductor-diodes-division/RS1B-E3-61T/1119066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 | EUR 0.51 | EUR 0.51
74 | D11 | D_SMA | 1 | SBM54ALAFC_R1_00001 | DigiKey | 3757-SBM54ALAFC_R1_00001CT-ND | Panjit International Inc. | SBM54ALAFC_R1_00001 | digikey.lu/en/products/detail/panjit-international-inc/SBM54ALAFC-R1-00001/14661142?s=N4IgTCBcDaIMoCECyBWALAQQDIYGIGEB9AJQEZCAGKi0kAXQF8g | EUR 0.39 | EUR 0.39
75 | U1 | SOT95P280X145-5N | 1 | ESDS314DBVR | DigiKey | 296-ESDS314DBVRCT-ND | Texas Instruments | ESDS314DBVR | digikey.lu/en/products/detail/texas-instruments/ESDS314DBVR/9655798?s=N4IgTCBcDaIKIGUAiCDMBGALEgQgNQCUQBdAXyA | EUR 0.60 | EUR 0.60
76 | U2 | Microchip-LAN8720AI-CP-TR-0-0-IPC_B | 1 | LAN8720A | DigiKey | LAN8720AI-CP-CT-ND | Microchip Technology | LAN8720AI-CP-TR | https://www.digikey.de/en/products/detail/microchip-technology/LAN8720AI-CP-TR/3872110 | EUR 1.95 | EUR 1.95 | JLCPCB link | https://lcsc.com/product-detail/Ethernet-ICs_Microchip-Tech-LAN8720AI-CP-TR_C17146.html
77 | U3 | MODULE_ESP32-WROOM-32D | 1 | ESP32-WROOM-32D | DigiKey | 1965-ESP32-WROOM-32D(4MBHIGHTEMP)CT-ND | Espressif Systems | ESP32-WROOM-32D (4MB HIGH TEMP) | https://www.digikey.lu/en/products/detail/espressif-systems/ESP32-WROOM-32D-4MB-HIGH-TEMP/12342929 | EUR 4.38 | EUR 4.38
78 | U4 | QFN28G_0.5-5X5MM | 1 | CP2102-GMR | DigiKey | 336-1160-1-ND | Silicon Labs | CP2102-GMR | https://www.digikey.lu/en/products/detail/silicon-labs/CP2102-GMR/2051863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 | EUR 5.27 | EUR 5.27
79 | U5 | AP62200WU-7 | 1 | AP62200WU-7 | DigiKey | 31-AP62200WU-7CT-ND | Diodes Incorporated | AP62200WU-7 | https://www.digikey.de/en/products/detail/diodes-incorporated/AP62200WU-7/10491524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 | EUR 0.45 | EUR 0.45
80 | U6 | QFN50P400X400X90-21N | 1 | SI3404-A-GM | DigiKey | 336-4270-ND | Skyworks Solutions Inc. | SI3404-A-GM | https://www.digikey.lu/en/products/detail/skyworks-solutions-inc/SI3404-A-GM/7897442 | EUR 3.51 | EUR 3.51
81 | U7 | SOIC254P1016X385-4N | 1 | FOD8173S | DigiKey | FOD8173S-ND | onsemi | FOD8173S | https://www.digikey.lu/en/products/detail/onsemi/FOD8173S/1049675 | EUR 0.59 | EUR 0.59
82 | U8 | SOT-23-5 | 1 | TLV431BSNT1G | DigiKey | TLV431BSNT1GOSCT-ND | onsemi | TLV431BSNT1G | https://www.digikey.lu/en/products/detail/onsemi/TLV431BSNT1G/921706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 | EUR 0.46 | EUR 0.46
83 | U9 | SOP50P310X90-8N | 1 | LSF0102DCUR | DigiKey | 296-39070-1-ND | Texas Instruments | LSF0102DCUR | https://www.digikey.de/en/products/detail/texas-instruments/LSF0102DCUR/4806525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 | EUR 0.79 | EUR 0.79
84 | Y1 | Crystal_SMD_2520-4Pin_2.5x2.0mm | 1 | 50MHz/DNP | DigiKey | 1908-O500-JO22-B-1V3-1-T1-LFCT-ND | Jauch Quartz | O 50,0-JO22-B-1V3-1-T1-LF | https://www.digikey.com/en/products/detail/jauch-quartz/O-50-0-JO22-B-1V3-1-T1-LF/10416318 | EUR 0.93 | EUR 0.93
85 | SW1, SW2 | PTS815SJM250SMTRLFS | 2 | SW_Push | DigiKey | CKN12215-1-ND | C&K | PTS815 SJM 250 SMTR LFS | https://www.digikey.de/en/products/detail/c-k/PTS815-SJM-250-SMTR-LFS/9947846 | EUR 0.19 | EUR 0.38
86 | JP1, JP2, JP3, JP4, JP7, JP8, JP9 | PinHeader_1x02_P2.54mm_Vertical | 7 | SolderJumper_2_Open | DigiKey | S1012EC-02-ND | Sullins Connector Solutions | PREC002SAAN-RC | https://www.digikey.lu/en/products/detail/sullins-connector-solutions/PREC002SAAN-RC/2774852 | EUR 0.06 | EUR 0.42
87 | Q5, Q6, Q7, Q8 | SOT-23 | 4 | 2N7002-7-F | DigiKey | 2N7002K-TPMSCT-ND | Micro Commercial Co | 2N7002K-TP | https://www.digikey.lu/en/products/detail/micro-commercial-co/2N7002K-TP/2641995 | EUR 0.30 | EUR 1.20
88 | Q1, Q2 | TRANS_SS8050-G | 2 | SS8050 | DigiKey | 641-1790-1-ND | Comchip Technology | SS8050-G | https://www.digikey.de/en/products/detail/comchip-technology/SS8050-G/6138901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 | EUR 0.30 | EUR 1.20
89 | Q3, Q4 | SSM3J377R_LF | 2 | SSM3J377R,LF | DigiKey | SSM3J377RLFCT-ND | Toshiba Semiconductor and Storage | SSM3J377R,LF | https://www.digikey.lu/en/products/detail/toshiba-semiconductor-and-storage/SSM3J377R-LF/9866020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 | EUR 0.45 | EUR 0.90
90 | RN1 | RESCAXS50P200X100X45_8N | 1 | 100R | DigiKey | Y7101CT-ND | Panasonic Electronic Components | EXB-28V101JX | https://www.digikey.de/en/products/detail/panasonic-electronic-components/EXB-28V101JX/256275 | EUR 0.10 | EUR 0.10
91 | TR1 | 749119933 | 1 | 749119950 | DigiKey | 732-2432-1-ND | Würth Elektronik | 749119950 | https://www.digikey.lu/en/products/detail/w%C3%BCrth-elektronik/749119950/2268633 | EUR 6.27 | EUR 6.27
92 | J3, J4 | 54601906WPLF | 2 | RJ12 | DigiKey | 609-4729-ND | Amphenol ICC (FCI) | 54601-906WPLF | https://www.digikey.lu/en/products/detail/amphenol-cs-fci/54601-906WPLF/4242891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 | EUR 0.55 | EUR 0.55
93 | J1 | BEL_1-2250024-1 | 1 | 1-2250024-1 | DigiKey | 1419-1063-ND | TRP Connector B.V. | 1-2250024-1 | https://www.digikey.lu/en/products/detail/trp-connector-b-v/1-2250024-1/8022853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 | EUR 8.55 | EUR 8.55
94 | J2 | USB4105-GF-A | 1 | USB4105-GF-A | DigiKey | 2073-USB4105-GF-ACT-ND | GCT | USB4105-GF-A | https://www.digikey.de/en/products/detail/gct/USB4105-GF-A/11198441 | EUR 0.84 | EUR 0.84
95 | J5 | PinHeader_1x08_P2.54mm_Vertical | 1 | POWER | DigiKey | 2057-PH1-08-UA-ND | Adam Tech | PH1-08-UA | https://www.digikey.de/en/products/detail/adam-tech/PH1-08-UA/9830442 | EUR 0.19 | EUR 0.19
96 | J6 | PinHeader_1x04_P2.54mm_Vertical | 1 | I2C Conn | DigiKey | 2057-PH1-04-UA-ND | Adam Tech | PH1-04-UA | https://www.digikey.lu/en/products/detail/adam-tech/PH1-04-UA/9829296 | EUR 0.10 | EUR 0.10
97 | J7 | PinHeader_1x06_P2.54mm_Vertical | 1 | GPIO | DigiKey | 2057-PH1-07-UA-ND | Adam Tech | PH1-07-UA | https://www.digikey.lu/en/products/detail/adam-tech/PH1-07-UA/9830505 | EUR 0.16 | EUR 0.16
98 | J10 | TerminalBlock_Phoenix_MPT-0,5-3-2.54_1x03_P2.54mm_Horizontal | 1 | Analog Sensor | DigiKey | ED10562-ND | On Shore Technology Inc. | OSTVN03A150 | https://www.digikey.lu/en/products/detail/on-shore-technology-inc/OSTVN03A150/1588863 | EUR 1.14 | EUR 1.14
99 | J11 | PinHeader_1x03_P2.54mm_Vertical | 1 | Pulse Sensor1 | DigiKey | 2057-PH1-03-UA-ND | Adam Tech | PH1-03-UA | https://www.digikey.lu/en/products/detail/adam-tech/PH1-03-UA/9830289 | EUR 0.10 | EUR 0.10
100 | J12 | PinHeader_1x03_P2.54mm_Vertical | 1 | Pulse Sensor2 | DigiKey | 2057-PH1-03-UA-ND | Adam Tech | PH1-03-UA | https://www.digikey.lu/en/products/detail/adam-tech/PH1-03-UA/9830289 | EUR 0.10 | EUR 0.10
 |  |  |  |  |  |  |  |  |  | total: | EUR 66.03

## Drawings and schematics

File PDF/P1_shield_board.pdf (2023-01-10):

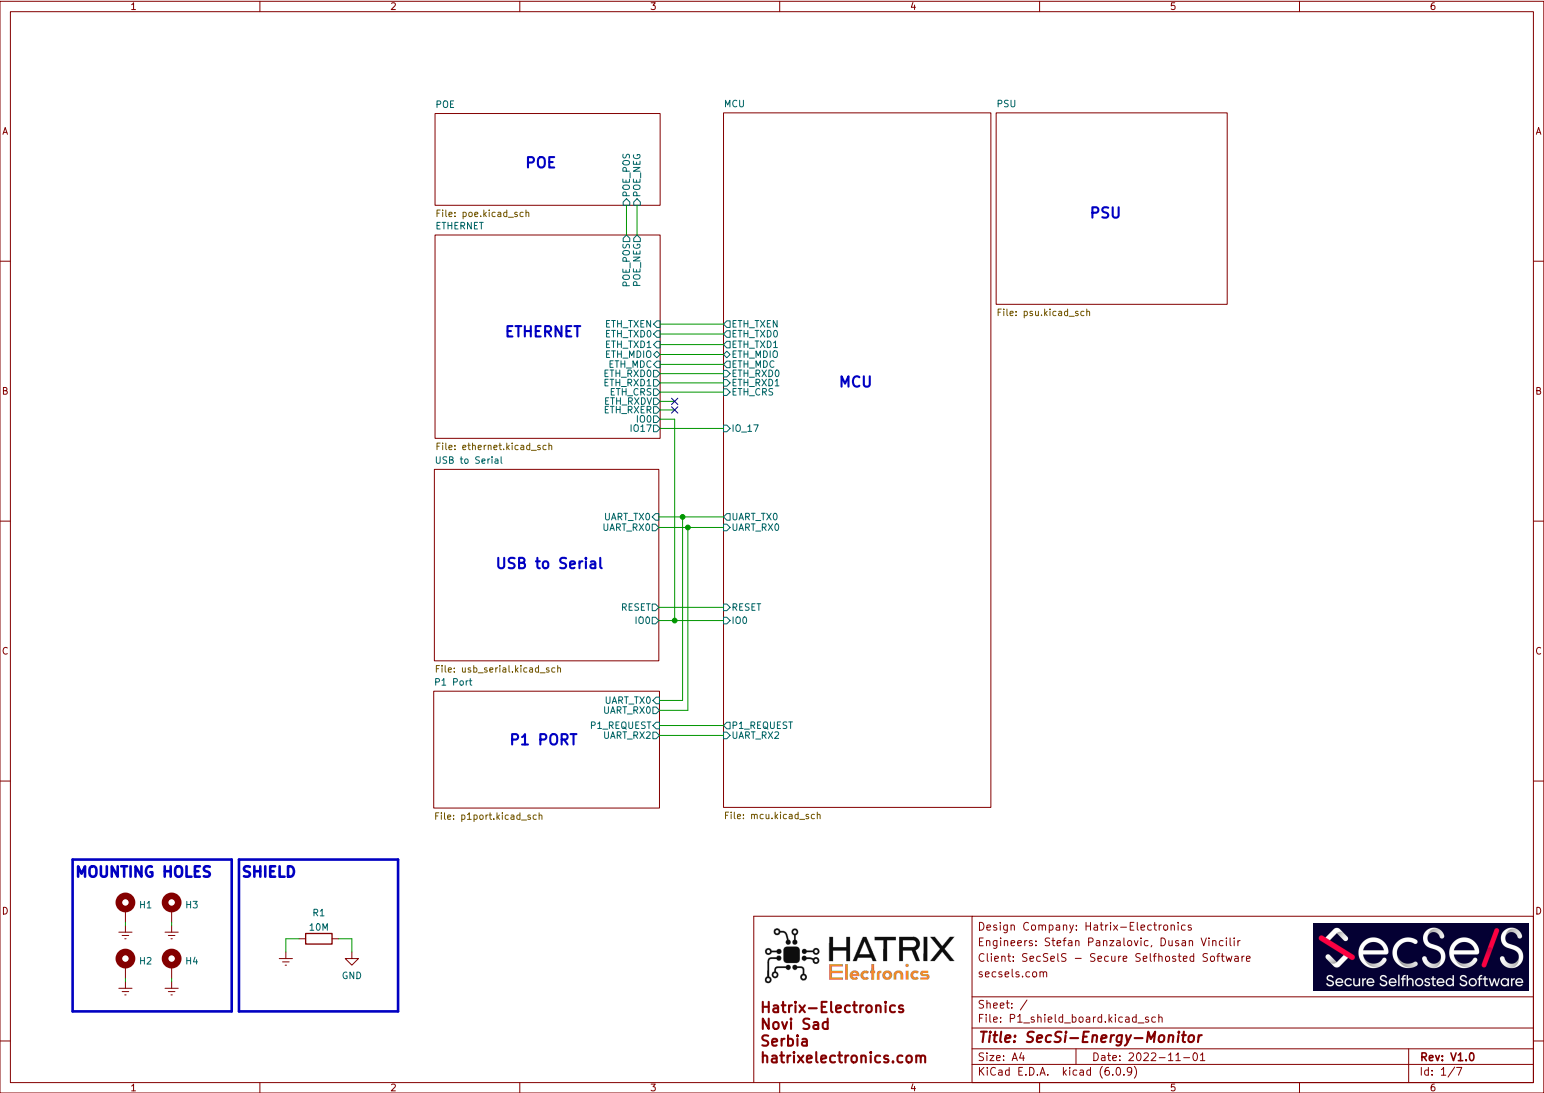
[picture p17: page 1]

File: mcu.kicad_sch P1_REQUEST UART_RX2 UART_TX0 UART_RX0 P1 Port File: p1port.kicad_sch

Design Company: Hatrix-Electronics
Client: SecSelS - Secure Selfhosted Software Engineers: Stefan Panzalovic, Dusan Vincilir

File: P1_shield_board.kicad_sch Sheet: / secsels.com

Id: 1/7 Title: SecSi-Energy-Monitor
Serbia

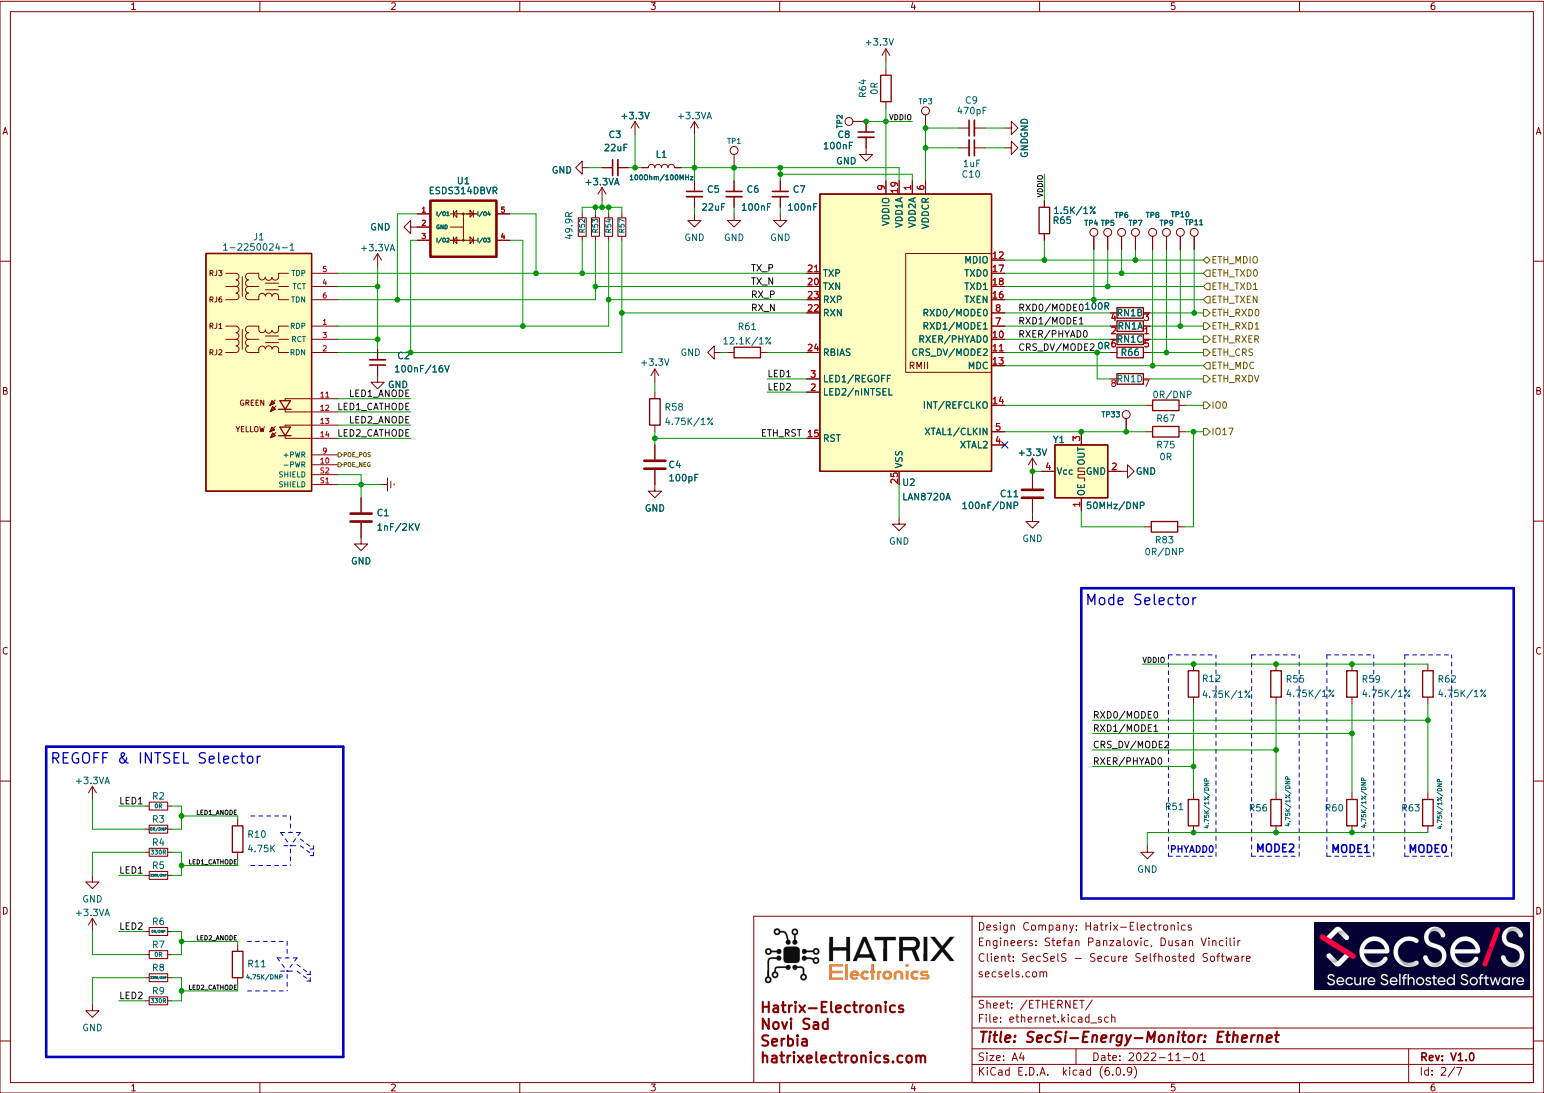
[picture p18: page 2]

+3.3V C6 TP4 GND R57 TP5TP6 C4

I/O1 1 GND 2

Design Company: Hatrix-Electronics
Client: SecSelS - Secure Selfhosted Software Engineers: Stefan Panzalovic, Dusan Vincilir

File: ethernet.kicad_sch Sheet: /ETHERNET/ secsels.com

Id: 2/7 Title: SecSi-Energy-Monitor: Ethernet

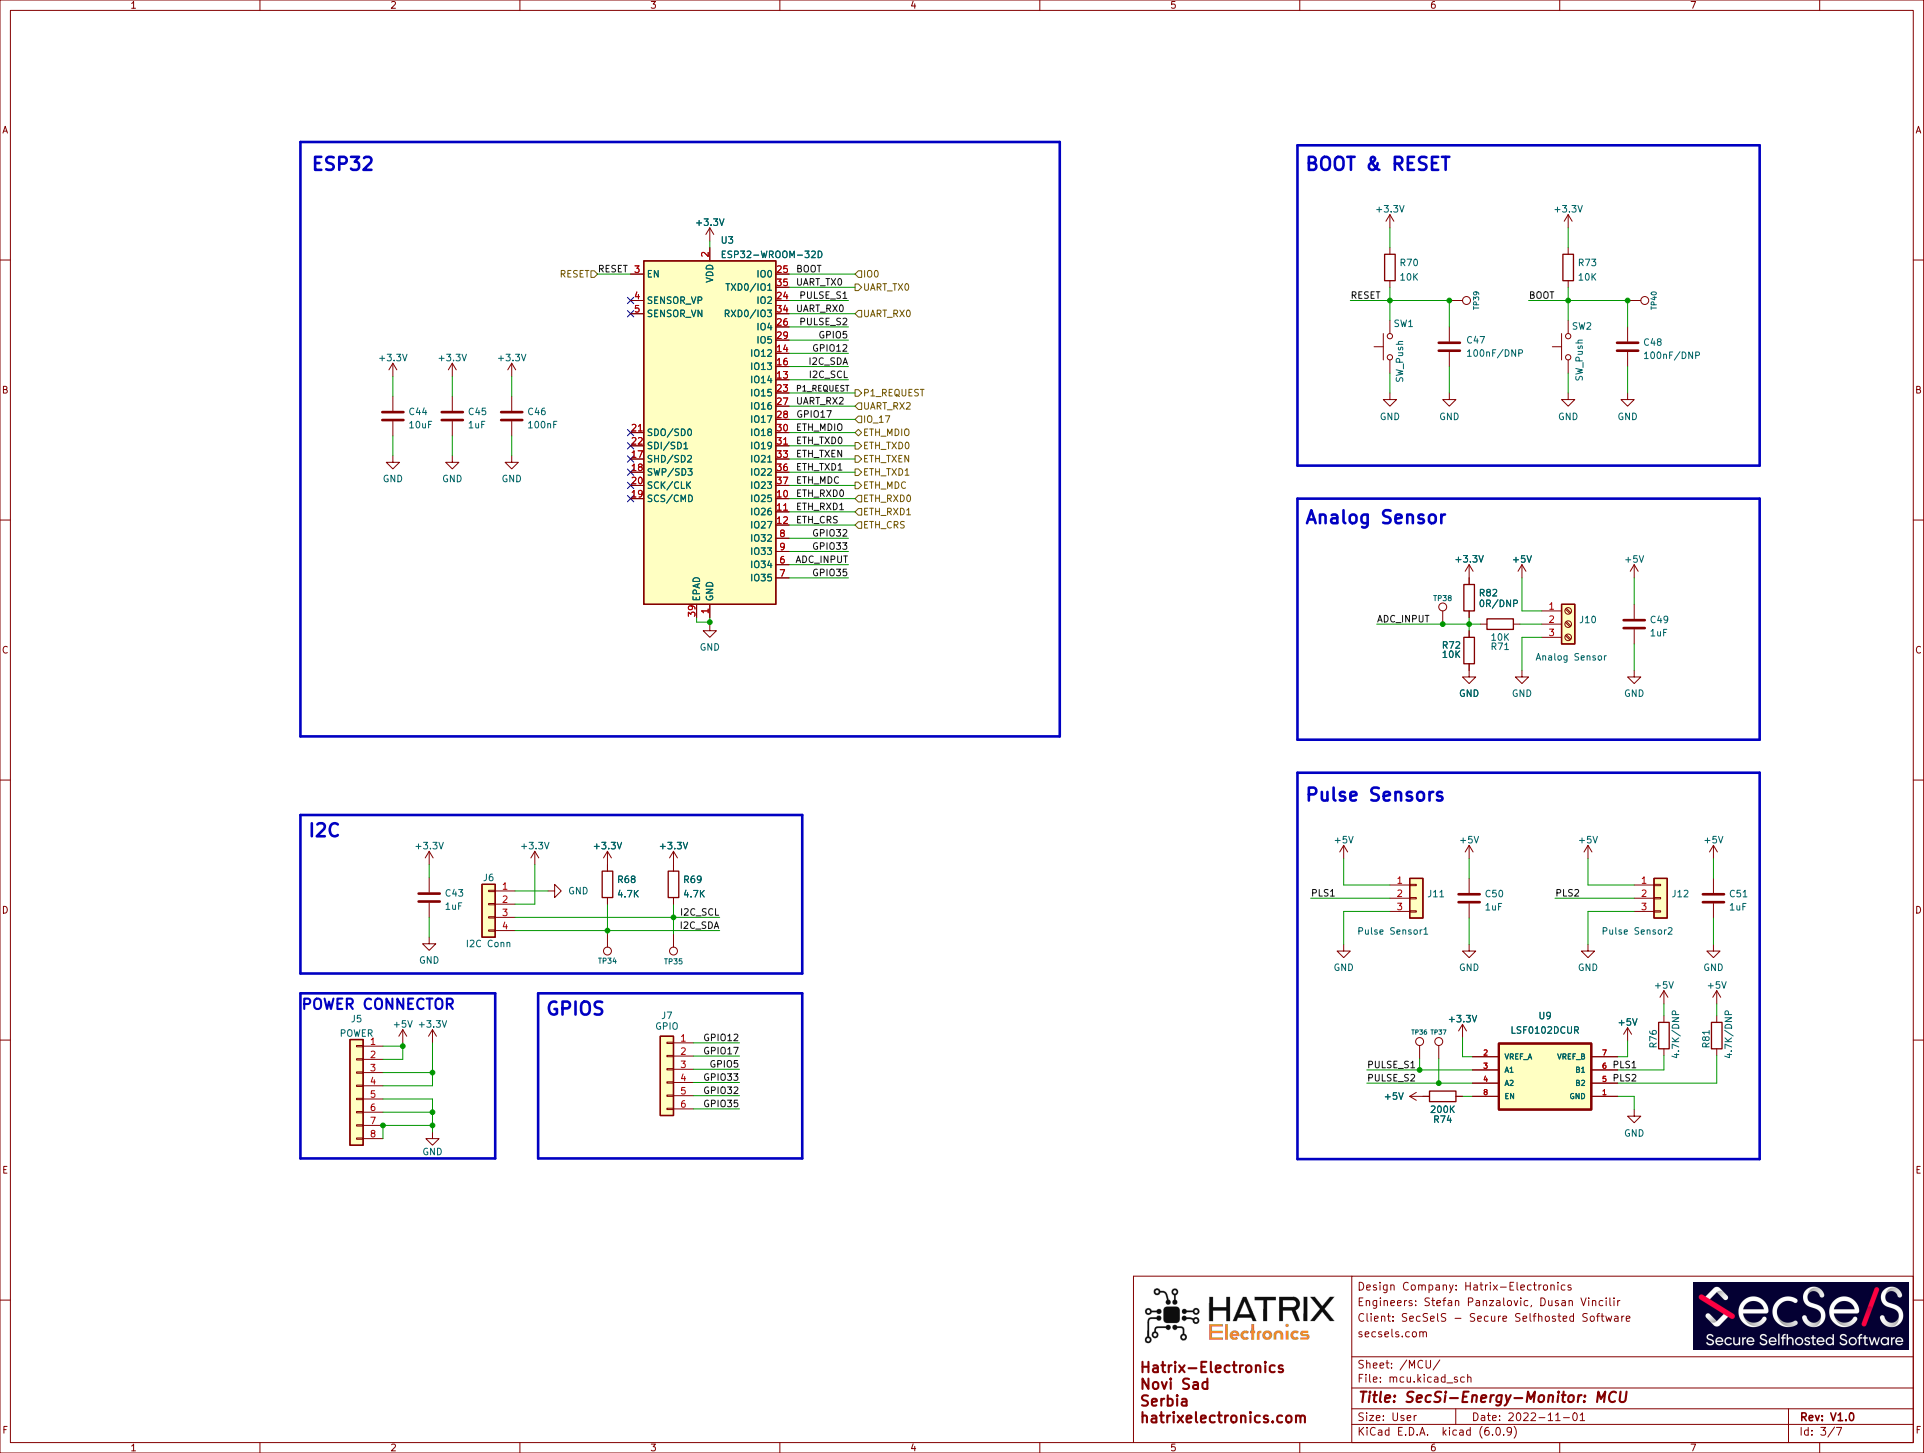
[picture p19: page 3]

2 SCK/CLK 20 SDO/SD0 21 SDI/SD1 22

Design Company: Hatrix-Electronics
Client: SecSelS - Secure Selfhosted Software Engineers: Stefan Panzalovic, Dusan Vincilir

File: mcu.kicad_sch Sheet: /MCU/ secsels.com

Id: 3/7 Title: SecSi-Energy-Monitor: MCU

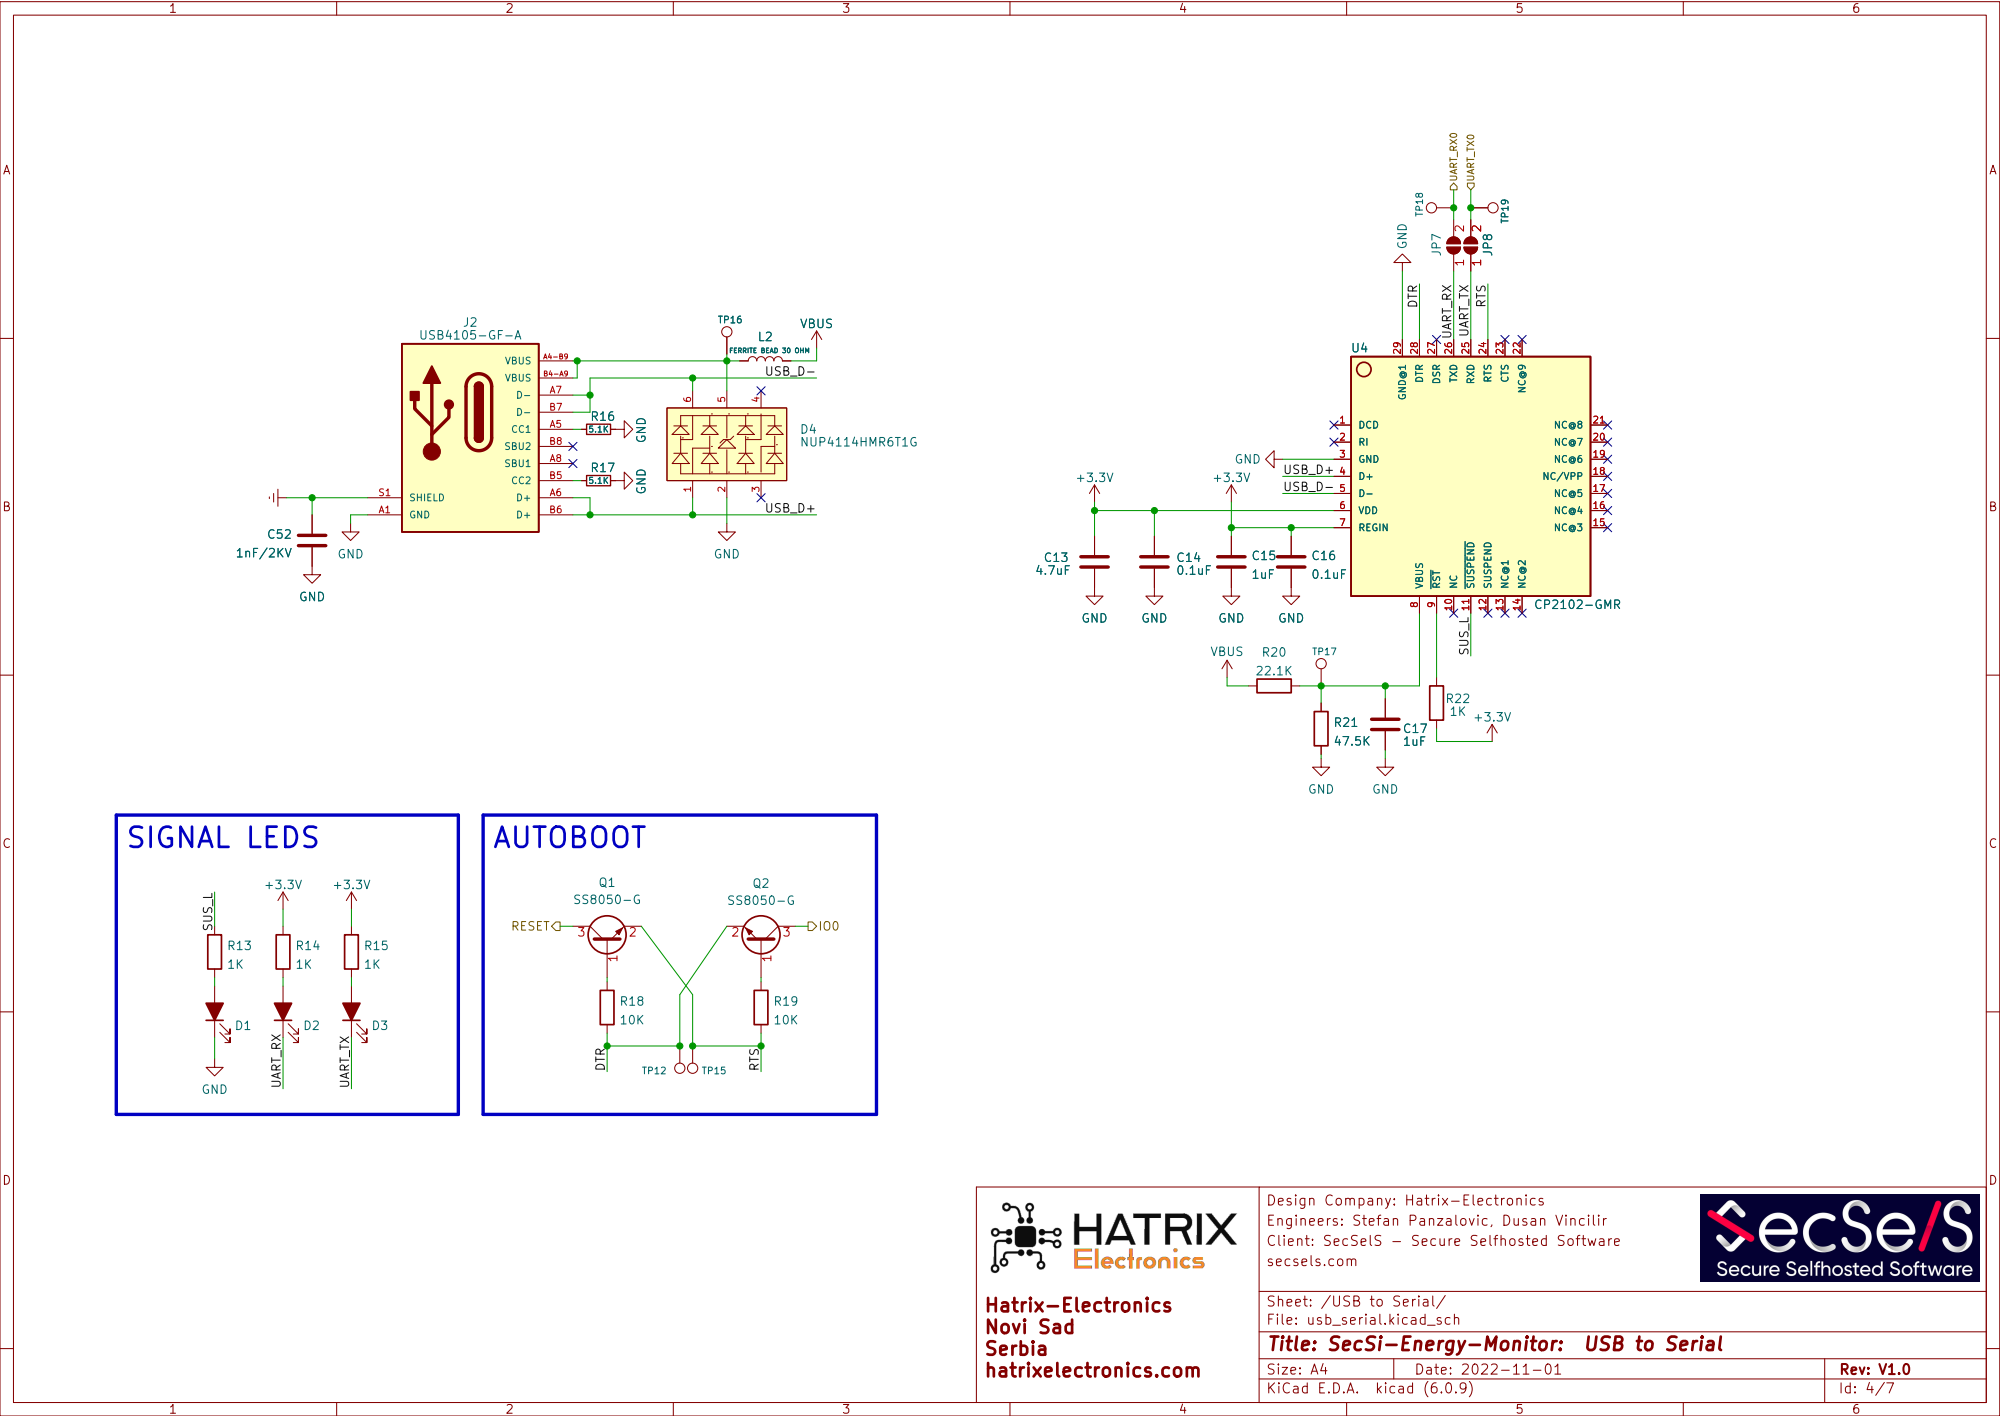
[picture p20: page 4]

Design Company: Hatrix-Electronics
Client: SecSelS - Secure Selfhosted Software Engineers: Stefan Panzalovic, Dusan Vincilir

File: usb_serial.kicad_sch Sheet: /USB to Serial/ secsels.com

Id: 4/7 Title: SecSi-Energy-Monitor: USB to Serial

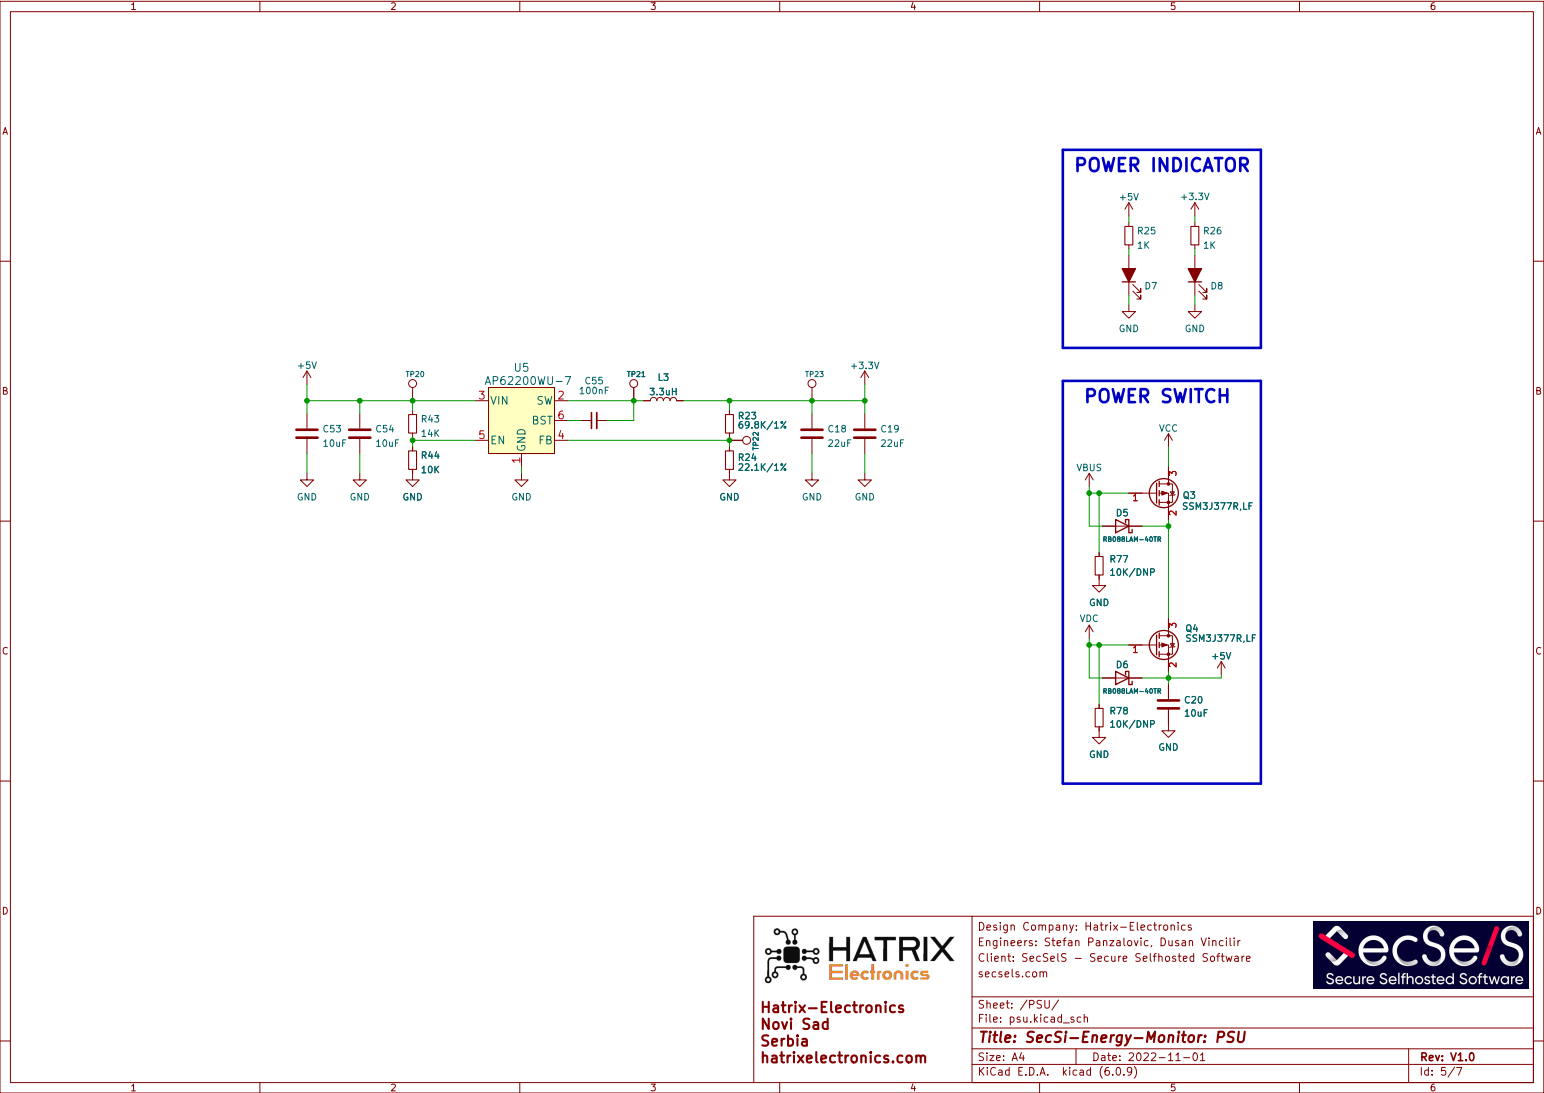
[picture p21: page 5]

1 SW 2 VIN 3 FB 4 EN 5 BST 6 U5 AP62200WU-7 R43

Design Company: Hatrix-Electronics
Client: SecSelS - Secure Selfhosted Software Engineers: Stefan Panzalovic, Dusan Vincilir

File: psu.kicad_sch Sheet: /PSU/ secsels.com

Id: 5/7 Title: SecSi-Energy-Monitor: PSU

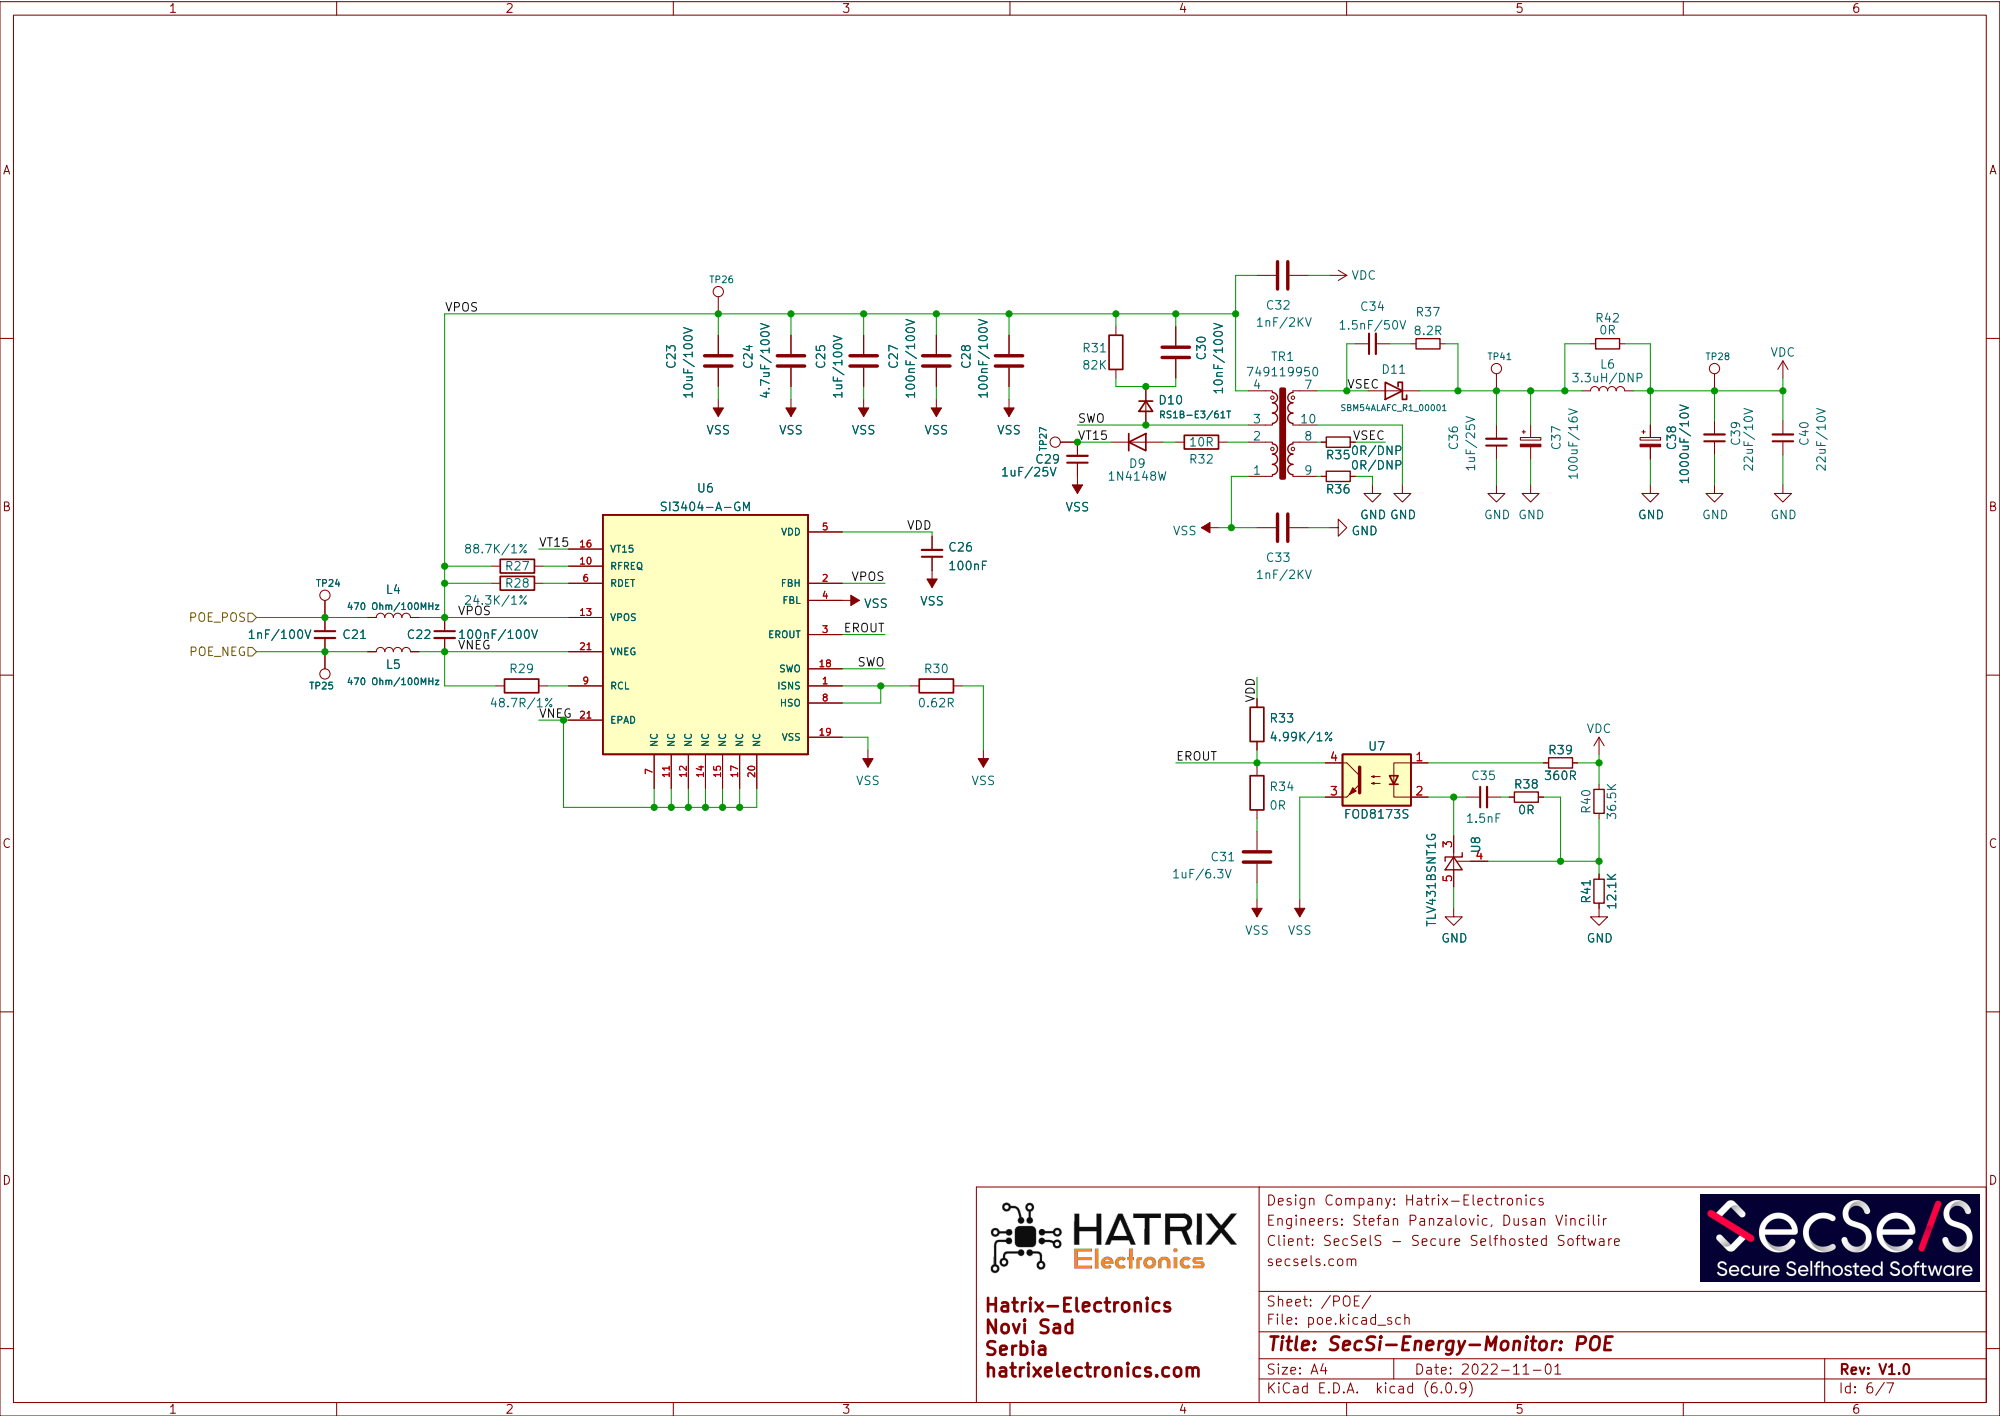
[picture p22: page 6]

Design Company: Hatrix-Electronics
Client: SecSelS - Secure Selfhosted Software Engineers: Stefan Panzalovic, Dusan Vincilir

File: poe.kicad_sch Sheet: /POE/ secsels.com

Id: 6/7 Title: SecSi-Energy-Monitor: POE

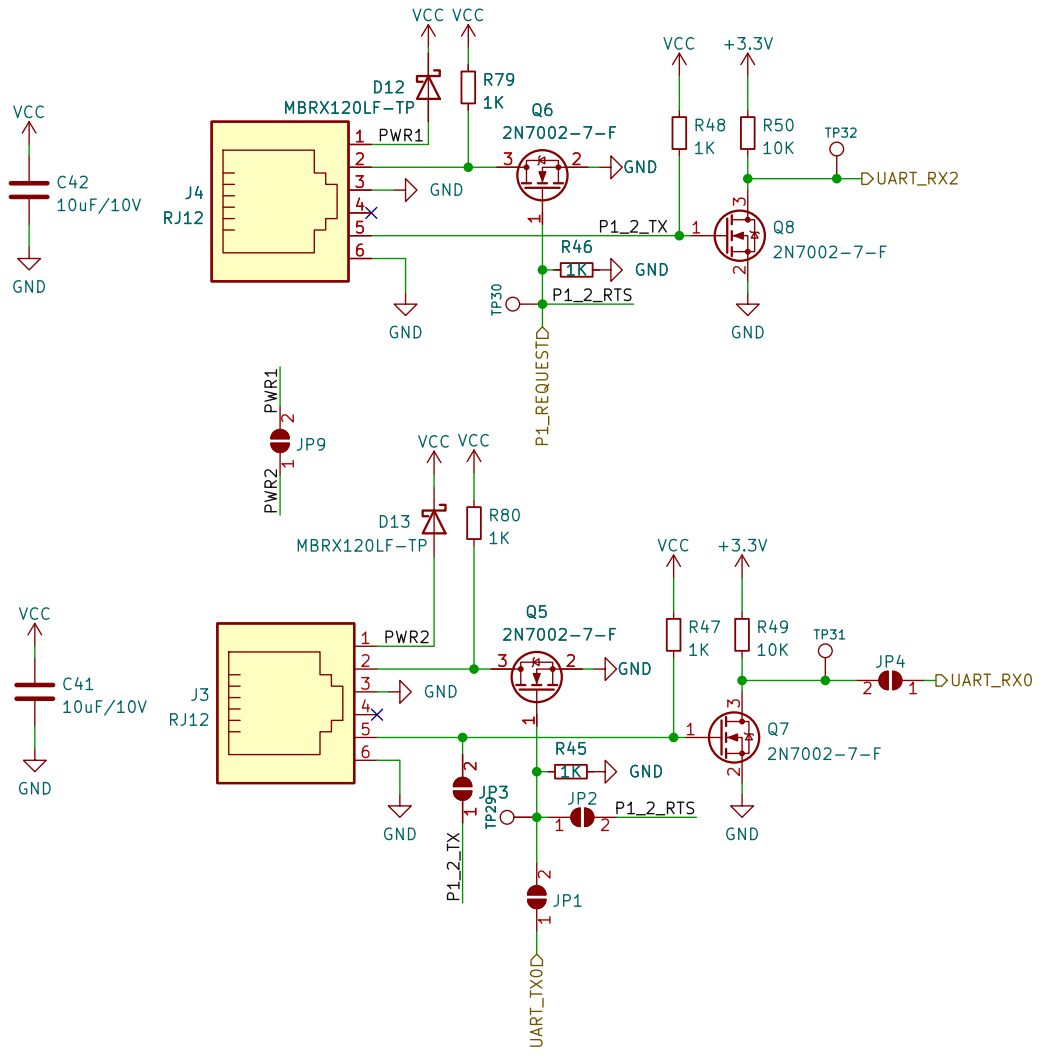
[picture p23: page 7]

Design Company: Hatrix-Electronics
Client: SecSelS - Secure Selfhosted Software Engineers: Stefan Panzalovic, Dusan Vincilir

File: p1port.kicad_sch Sheet: /P1 Port/ secsels.com

Id: 7/7 Title: SecSi-Energy-Monitor: P1 Port

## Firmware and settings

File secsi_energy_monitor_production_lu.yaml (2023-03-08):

substitutions:
  name: secsi-energy-monitor
  friendly_name: secsi-energy-monitor
  device_description: Energy meter by secsels.com
  ap_fallback_password: secsi-device
  dashboard_import_url: github://SecSelS/SecSi-Energy-Monitor/secsi_energy_monitor_production_lu.yaml@main
     
esphome:
  name: ${name}
  name_add_mac_suffix: false
  friendly_name: ${friendly_name}
  comment: "${device_description}"

esp32:
  board: esp32dev
  framework:
    type: arduino

wifi:
# Enable fallback hotspot (captive portal) in case wifi connection fails.
# If you don't use dashboard_import, make sure to uncomment the wifi networks.
#  networks:
#    - ssid: !secret wifi_ssid
#      password: !secret wifi_password
  ap:
    ssid: ${name}
    password: ${ap_fallback_password}
    ap_timeout: 15s
 
captive_portal:

# If you want to use ethernet, uncomment the following (make sure to remove all above wifi related settings and sensors)

#ethernet:
#  type: LAN8720
#  mdc_pin: GPIO23
#  mdio_pin: GPIO18
#  clk_mode: GPIO17_OUT
#  phy_addr: 1
 
# Disable serial logging
logger:
  baud_rate: 0
 
# Enable Home Assistant API
api:
# optional use of encryption key
#  encryption:
#    key: !secret encryption_key

ota:
  safe_mode: true
# Optional use of OTA-Password
#  password: !secret ota_password
#  encryption:
#    key: !secret encryption_key

web_server:
  port: 80
  
# Here the UART-Pins are defined for the p1 ports
# As the p1 only has rx, only these are defined
uart:
  - rx_pin:
      number: GPIO16
    baud_rate: 115200
    rx_buffer_size: 1700
    id: uart_p1_1
    
# Here the second P1 UART is defined (just uncomment if you use second p1)

#   - rx_pin:
#      number: GPIO3
#    baud_rate: 115200
#    rx_buffer_size: 1700
#    id: uart_p1_2

dsmr:
  - uart_id: uart_p1_1
    id: dsmr_p1_1_key
    decryption_key: !secret dsmr_key_p1_1
    max_telegram_length: 1700
    
# Here the second P1 UART DSMR Key is defined (just uncomment if you use second DSMR encrypted P1 port)

#  - uart_id: uart_p1_2
#    id: dsmr_p1_2_key
#    decryption_key: !secret dsmr_key_p1_2
#    max_telegram_length: 1700
 
sensor:
  - platform: dsmr
    dsmr_id: dsmr_p1_1_key
    energy_delivered_lux:
      name: "Energy Consumed"
      state_class: total_increasing
    energy_delivered_tariff1:
      name: "Energy Consumed Tariff 1"
      state_class: total_increasing
    energy_delivered_tariff2:
      name: "Energy Consumed Tariff 2"
      state_class: total_increasing
    energy_returned_lux:
      name: "Energy Produced"
      state_class: total_increasing
    energy_returned_tariff1:
      name: "Energy Produced Tariff 1"
      state_class: total_increasing
    energy_returned_tariff2:
      name: "Energy Produced Tariff 2"
      state_class: total_increasing
    power_delivered:
      name: "Power Consumed"
      accuracy_decimals: 3
    power_returned:
      name: "Power Produced"
      accuracy_decimals: 3
    electricity_failures:
      name: "Electricity Failures"
      icon: mdi:alert
    electricity_long_failures:
      name: "Long Electricity Failures"
      icon: mdi:alert
    voltage_l1:
      name: "Voltage Phase 1"
    voltage_l2:
      name: "Voltage Phase 2"
    voltage_l3:
      name: "Voltage Phase 3"
    current_l1:
      name: "Current Phase 1"
    current_l2:
      name: "Current Phase 2"
    current_l3:
      name: "Current Phase 3"
    power_delivered_l1:
      name: "Power Consumed Phase 1"
      accuracy_decimals: 3
    power_delivered_l2:
      name: "Power Consumed Phase 2"
      accuracy_decimals: 3
    power_delivered_l3:
      name: "Power Consumed Phase 3"
      accuracy_decimals: 3
    power_returned_l1:
      name: "Power Produced Phase 1"
      accuracy_decimals: 3
    power_returned_l2:
      name: "Power Produced Phase 2"
      accuracy_decimals: 3
    power_returned_l3:
      name: "Power Produced Phase 3"
      accuracy_decimals: 3
    gas_delivered:
      name: "Gas Consumed"
      state_class: total_increasing
# Belgium Sensor (uncomment for belgium Meter)
#    gas_delivered_be:
#      name: "Gas Consumed"
#      state_class: total_increasing
  - platform: uptime
    name: "${name} Uptime"
  - platform: wifi_signal
    name: "${name} Wi-Fi Signal"
    update_interval: 60s
    
# For the usage of a second P1 Meter, make sure you define additional sensors with the correct id you want to use.
# For every platform, you have to use a seperate dsmr id, matching the dsmr key of your plugged meter.
# See example below. Do the same for text_sensor:

#  - platform: dsmr
#    dsmr_id: dsmr_p1_2_key
#    energy_delivered_lux:
#      name: "Energy Consumed"
#      state_class: total_increasing
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
